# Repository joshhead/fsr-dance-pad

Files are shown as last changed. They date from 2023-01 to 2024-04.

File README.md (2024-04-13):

# FSR Dance Pad with Aluminum Frame

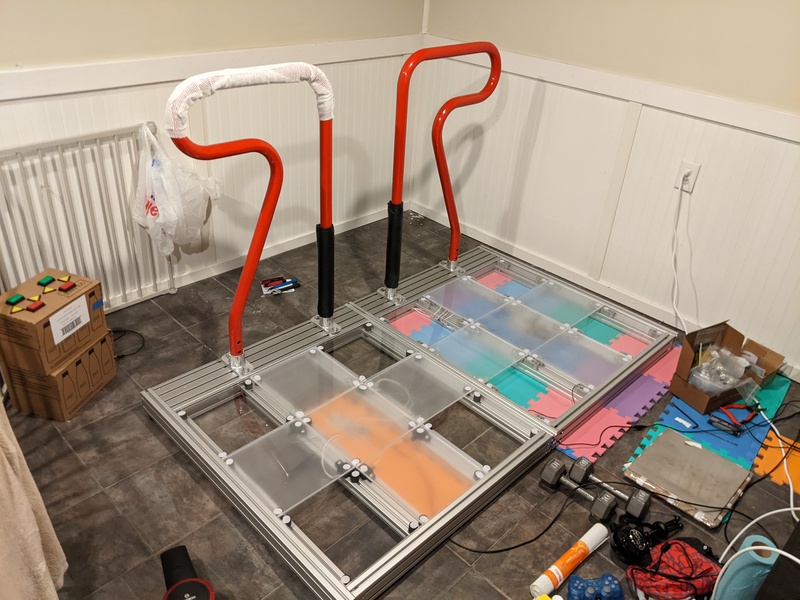
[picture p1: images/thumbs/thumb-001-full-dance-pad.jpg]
assembled dance pad
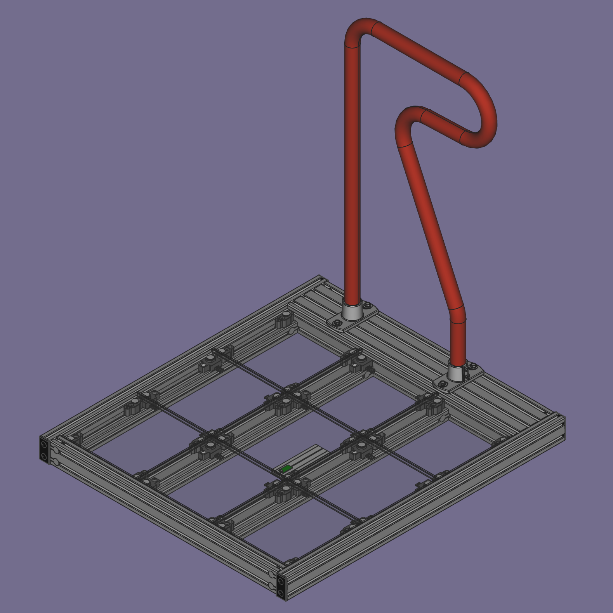
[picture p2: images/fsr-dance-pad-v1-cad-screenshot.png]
dance pad CAD model
[](./images/001-full-dance-pad.jpg) [](./freecad)

# Acknowledgements

This pad is essentially a fork of the RE:Flex dance pad (V2), with FSRs and teejusb's firmware.

I initially set out to build a RE:Flex, but ultimately made some changes.

My goals were

1. reduce BOM cost
2. support an arcade-style bar
3. minimize pad height to accomodate a low ceiling in my basement

Many of my design decisions were inspired and informed by ideas in the original RE:Flex, and even where I am happy with my changes, I'm usually giving up some desirable property in exchange. In several cases, trying to alter the design just made me realize why it was done that way in the first place. :)

# Differences from RE:Flex

* My frame is built with 15 series aluminum extrusions, which are 1.5 inches wide (38.1 mm). RE:Flex uses 40mm extrusions. TNutz was the cheapest hardware supplier I could find in the U.S. by a significant margin, and they do not carry 40mm extrusions, so I converted the frame to 15 series.
* My frame is assembled with anchor fasteners. RE:Flex uses joining plates on the bottom as well as inside corner gussets. The anchor fasteners save a small amount of height since there are no screws and joining plates underneath. It also allows the whole frame to sit flat on a foam mat since the bottom is all flush. When the frame is supported only at the corners (by rubber feet), I find it sqeaks. The joining plate plus corner gusset combo may do a better job of resisting twisting forces. The anchor fasteners require fewer screws, but also require machining on the extrusions.
* My pads include a set of Pump it Up GX bars, which I was lucky enough to snag on eBay after someone in the RE:Flex Discord pointed them out. They are mounted with railing flanges I found that happen to be the right size to fit both the bar and the extrusion. This meant getting beefy 3" by 6" extrusions for the back of the pads, which looks cool but increased the cost. I was super pleased to find that it all fits together well and feels sturdy. It would probably be more comfortable if it was height-adjustable, wider, and an inch or two further forward, which the RE:Flex bar does all of, so I'm not sure if this change was worth it! It was fun to design though. If you are unable to source an arcade bar but wanted to keep this form factor, you could build your own bar with pipe and elbow connectors.
* I modified the active and inactive panels to be flush with each other. RE:Flex inactive panels are 1mm higher than the active panels. This is nice for playing in socks, and less so in shoes since I can't feel where the panels are.
* Single-piece inactive panel standoffs. RE:Flex standoffs have some pieces that can be reused when switching from inactive to active panels, or iterating on the design. I came up with something that uses a little less plastic and can be printed in a single piece. It's also symmetrical so I don't need to worry about "left" and "right" versions. It sacrifices something in aesthetics since it looks a lot different from the active panel standoffs.
* Completely different electronics. The RE:Flex lighting looks amazing and its load cell based sensors have greater range and precision than the FSRs in my pad. However, due partly to the sweet lights and partly to semiconductor shortages, the cost of the RE:Flex electronics was very high in mid-2021, if you could even get all the parts. For a while I wanted 9 active panels, which RE:Flex didn't support yet (and still doesn't as of January 2023, but it is planned eventually).

# Other Designs

RE:Flex https://reflex.dance/

teejusb's FSR software https://github.com/teejusb/fsr

Dance pad by root670 https://github.com/root670/dance-pad

Bandit's travel pad (Build This Travel Pad) https://www.youtube.com/watch?v=y6wGYLE0YI4

Azirixx's build of Bandit's travel pad https://github.com/azirixx/easy-travel-pad-build

Sereni's FSR dance pad https://sereni.github.io/fsr-pad-guide/

Dom ITG's FSR dance pad https://www.youtube.com/playlist?list=PL2vUwLUVuyIy4CD8DEwS7oZ_Y41vyYWWy

Nato's metal travel pad https://github.com/natologic/MetalTravelPad

# Cost

I built two pads in the USA between 2021 and 2022 for around $1750 total.

# Bill of Materials

(See sourcing guide [here](./sourcing-guide.md) for product links and additional commentary.)

Frame Extrusions:
| Quantity | Profile | Length | Machining |
| --- | --- | --- | --- |
| 2 | 1515 (1.5" x 1.5") | 33 3/8"  | 4x counterbore |
| 2 | 1530 (1.5" x 3.0") | 33 3/8"  | 4x counterbore |
| 2 | 1530 (1.5" x 3.0") | 40 7/8"  | none |
| 1 | 1530 (1.5" x 3.0") | 33 3/8"  | 6x counterbore |
| 1 | 3060 (3.0" x 6.0") | 33 3/8"  | 6x counterbore |

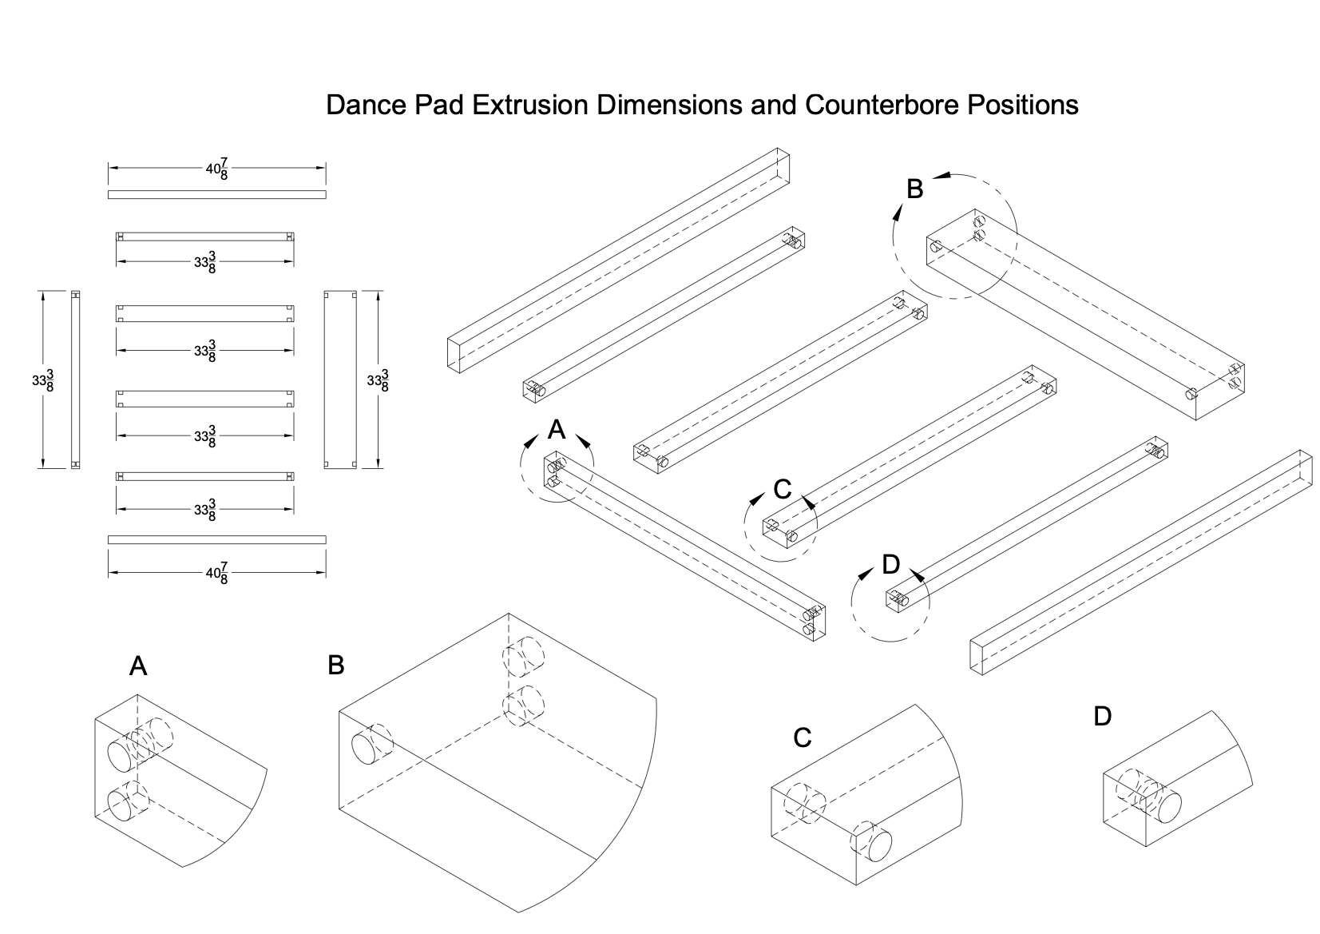
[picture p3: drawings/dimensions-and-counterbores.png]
dimensions and counterbores drawing


Frame Fasteners:
* 4 double anchor fastener assemblies for 1515 struts
* 4 wide double anchor fastener assemblies for 1530 struts
* 12 single anchor fastener assemblies for front and back

Frame support:

* Foam or rubber mat to support pad

  OR

* 4 rubber feet, 4 screws, 4 t nuts

  OR

* 4 leveling feet of some kind

Bar Assembly:
* 1 Pump It Up bar or DIY bar (use nominal 1 1/4" pipe, outer diameter of 1.66")
* 2 Hollaender® - Safety Rail Fitting - 1-1/4in. Base Flange Strctrual Slip-on Fitting
* 4 t nuts, 4 washers, 4 screws (5/16"-18 7/8"long)
* 2 3D printed screw aligners

Panels and standoffs:
* 9 11" x 11" x 0.472" (12mm) cast acrylic panels
* 36 t-nuts and 36 5/16-18 x 1" Button Head Socket Cap Screws to attach standoffs
* 20 3D printed inactive panel standoffs
* 16 3D printed active panel FSR holders
* 16 3D printed active panel standoffs
* 16 3D printed active panel standoff holders (8 of standoff-holder.stl and 8 of standoff-holder-mirrored.stl)
* 16 rubber bumpers with adhesive backing, 1/2" OD, 1/16" thick
* 36 pairs of hook and loop fastener circles, 20mm diameter (36 hook, 36 loop)

Sensors and electronics:
* 1 Teensy LC with pins
* 1 10ft USB micro cable
* Some 330 ohm resistors, the exact value isn't that important, anything 100 ohm to 1000 ohm is probably usable.
* 22awg solid core hookup wire
* 1 Solderless breadboard
* 16 Interlink FSR 402 Short FSRs with female connector with housing
* 1 3D printed breadboard platform
* 2 t nuts and 2 screws (5/16"-18 5/8" long) for breadboard platform
* Small zip ties
* 3D printed cable management clips

Tools:
* 3D printed hook and loop fastener aligners
* 3D printed strut spacers
* 3D printed standoff spacers
* Ball-end hex allen keys
* Wire cutters
* Wire strippers
* Deburring tool

# Build Instructions

Up front you'll need a 3D printed spacing tool for the struts and a round hex ball wrench.

First gather your parts and deburr them. I used needle nose pliers to pull off the big chunks and deburring tool to smooth out some rough edges. The anchors will not fit properly if there is too much debris. Remember that the deburring tool has two different angles on it and dragging it in one direction will cut deeper. I didn't find this to be as big of an issue as on plastic parts but it is still useful to be aware of.

Lay out your extrusions as they will be arranged. Check their orientation. Maybe some are scratched. Decide where you want the scratches to go.

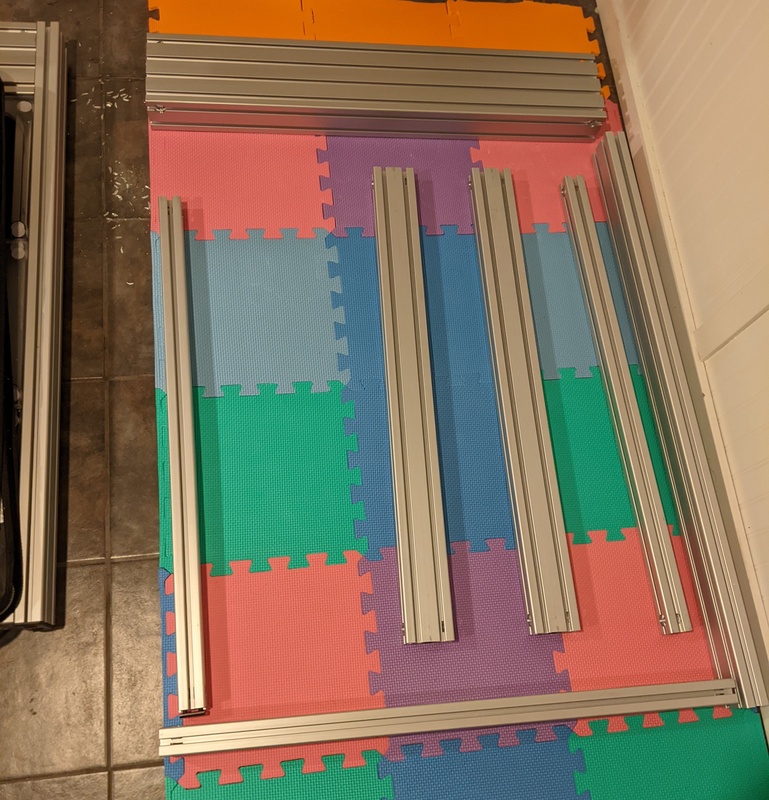
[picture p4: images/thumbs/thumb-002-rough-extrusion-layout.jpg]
rough extrusion layout


If you are using slide-in t nuts to attach the bar, feet, panel standoffs, breadboard platform, or any other accessories, insert them all now! They can't be added after joining the extrusions together. Roll-in t nuts are more expensive, but very convenient since they give you flexibility in the order of assembly or to add things on later. I used some heavy duty slide-in t nuts for the bar which I inserted at this point.

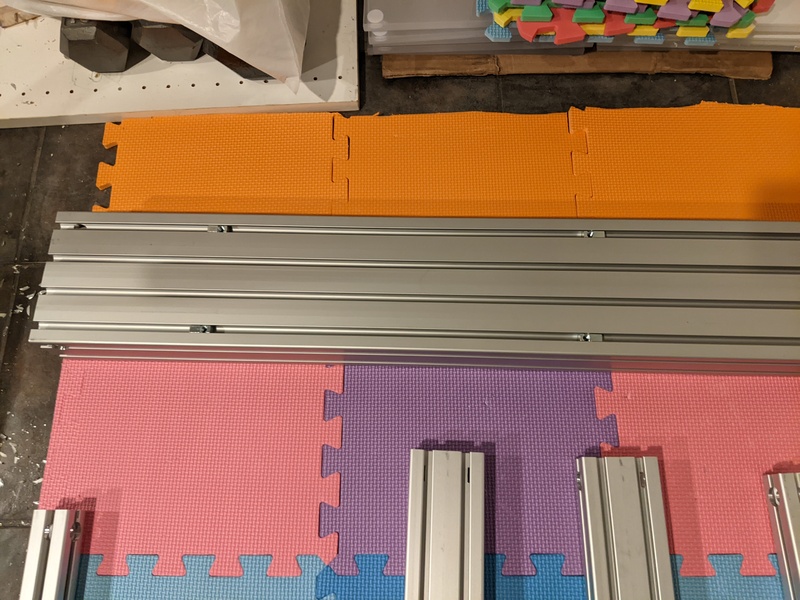
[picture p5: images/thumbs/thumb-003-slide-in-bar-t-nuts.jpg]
slide in bar t nuts


Gather your anchor fastener assemblies. Make sure they all match up and you have enough.

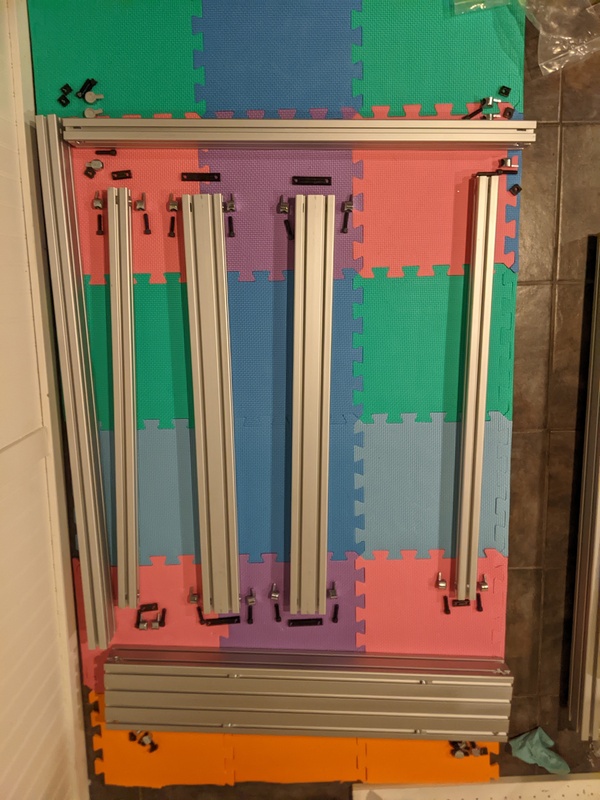
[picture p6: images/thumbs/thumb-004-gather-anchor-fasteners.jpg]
gather anchor fasteners


Assemble the anchor fasteners on the ends of the extrusions that have been machined to fit them. Pay attention to the direction of the t nuts. I put them on backwards a few times. Easy fix but annoying. Screw them together just slightly; they need to slide into place.

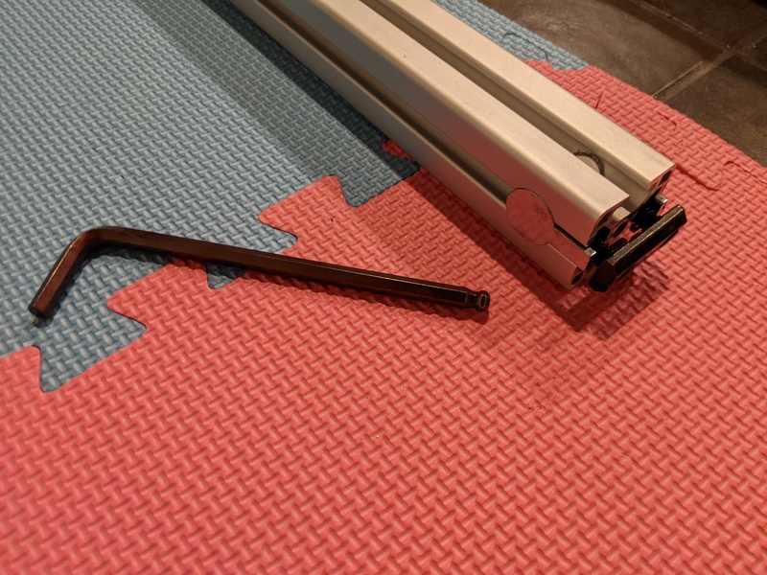
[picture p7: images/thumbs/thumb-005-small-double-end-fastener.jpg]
small double end fastener

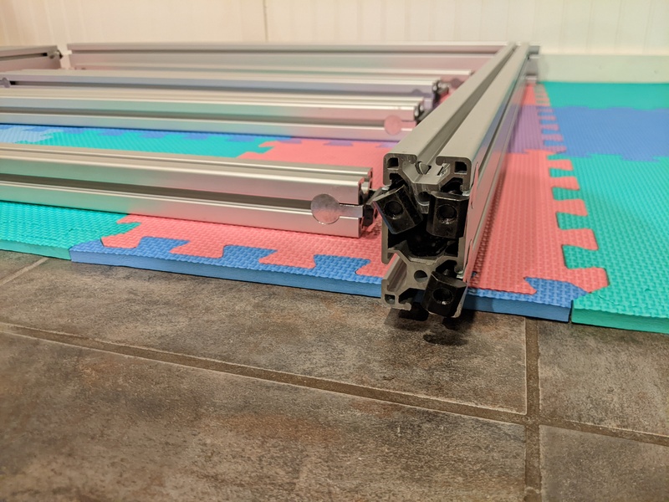
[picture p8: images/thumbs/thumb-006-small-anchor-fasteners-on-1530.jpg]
small anchor fasteners on 1530

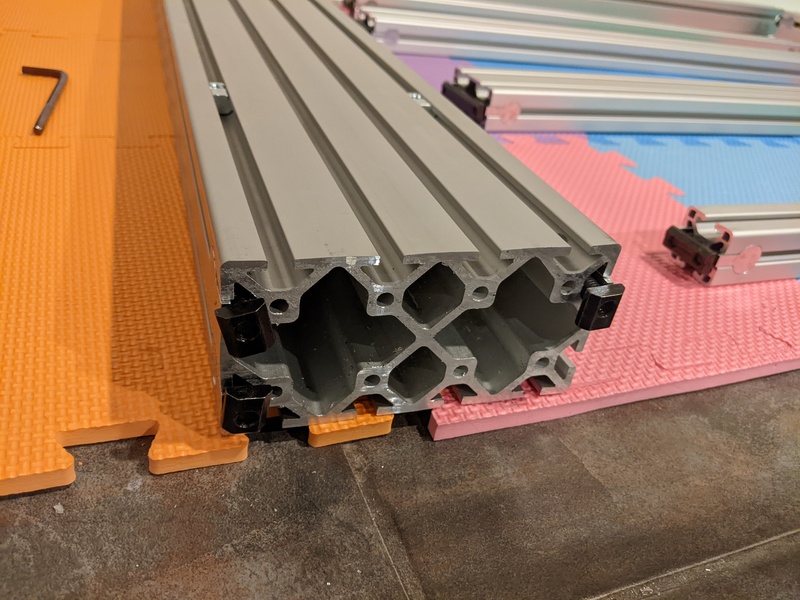
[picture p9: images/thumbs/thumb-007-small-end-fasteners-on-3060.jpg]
small end fasteners on 3060

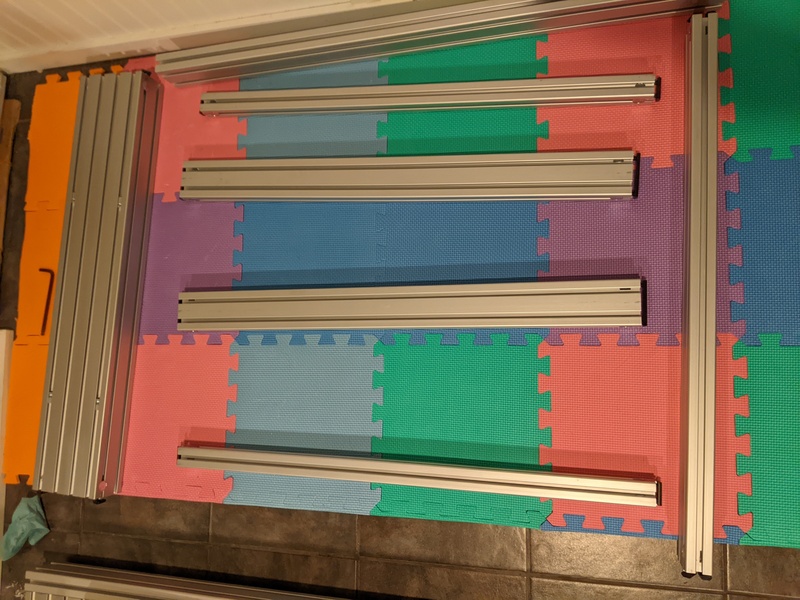
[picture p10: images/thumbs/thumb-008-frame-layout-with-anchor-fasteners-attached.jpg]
frame layout with anchor fasteners attached


Slide the four struts into the back and front extrusions. Or, depending on your perspective, slide the back and front pieces onto the struts. I had to loosen some of the screws a little bit; if they are too tight, the extrusions will not slide together.

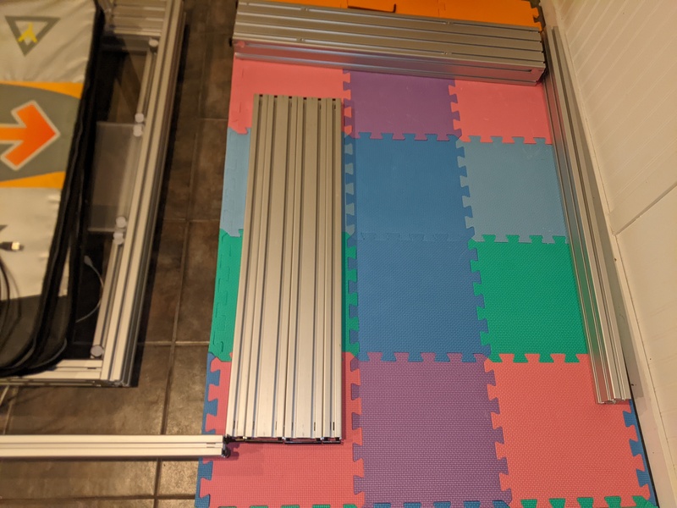
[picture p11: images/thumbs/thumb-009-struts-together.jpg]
struts together

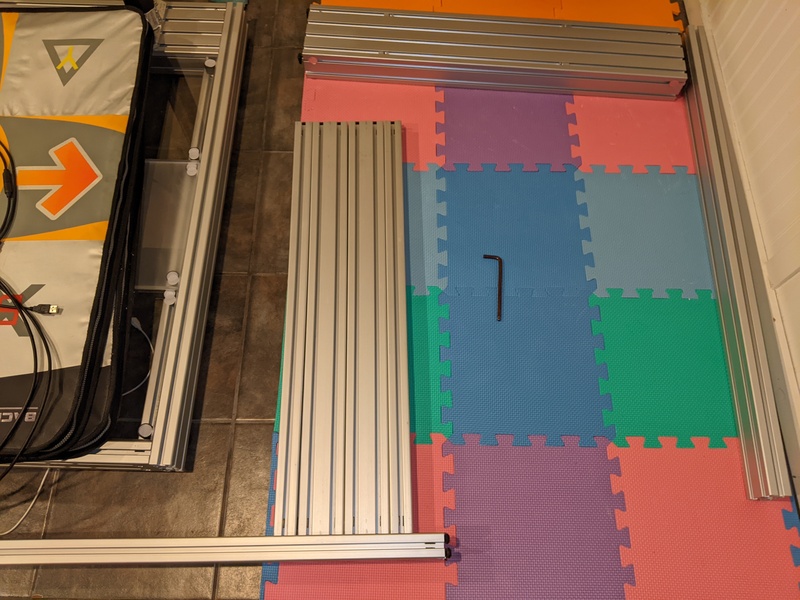
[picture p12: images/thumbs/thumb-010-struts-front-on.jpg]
struts front on

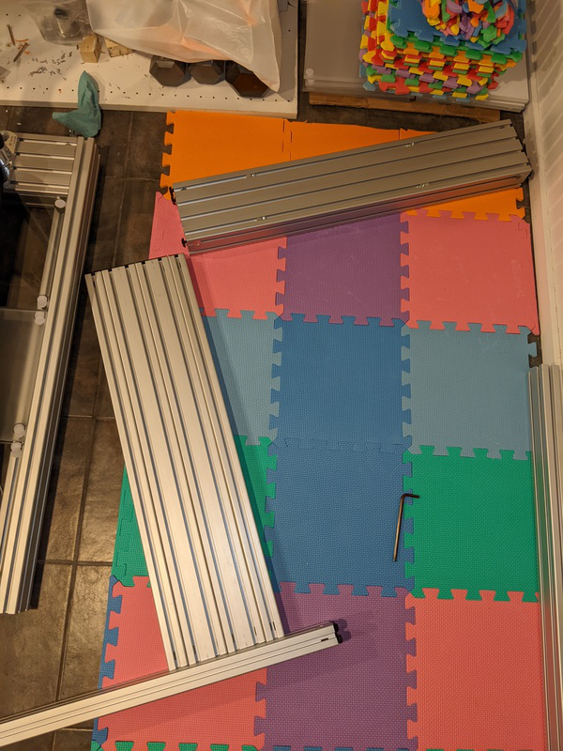
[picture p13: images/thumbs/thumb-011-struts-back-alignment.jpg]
struts back alignment

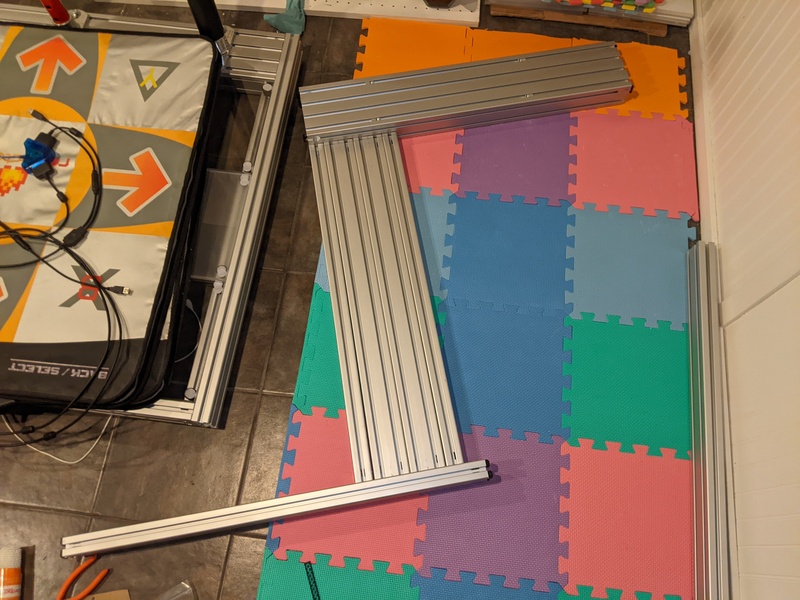
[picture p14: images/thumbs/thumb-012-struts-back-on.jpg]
struts back on

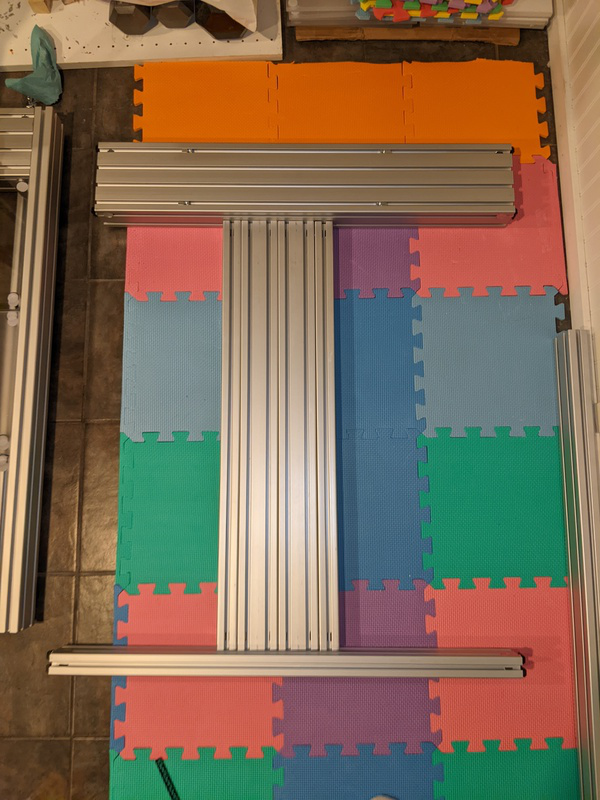
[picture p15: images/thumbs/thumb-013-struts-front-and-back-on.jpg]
struts front and back on


Now attach the left and right sides by sliding them on. In the pictures, I have only one side, because I am sharing a center piece between the player one and player two pads.

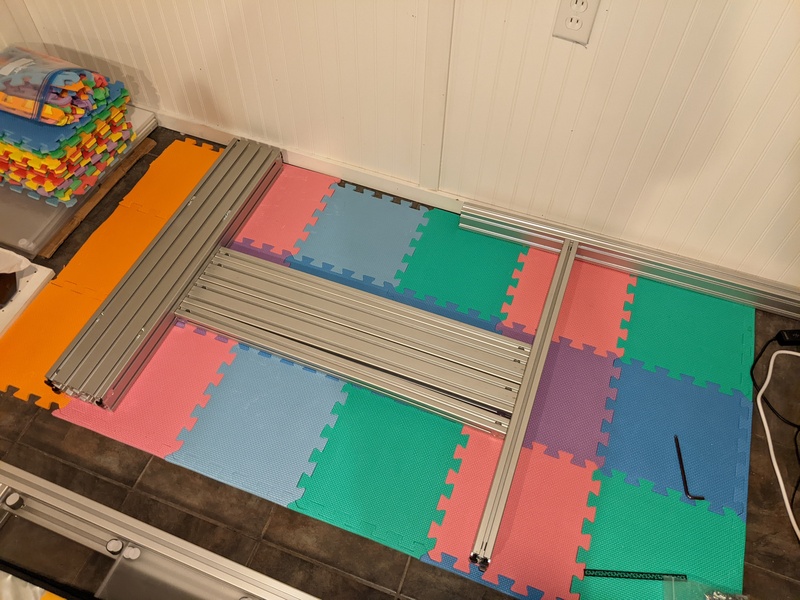
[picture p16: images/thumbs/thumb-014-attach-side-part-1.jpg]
attach side part 1

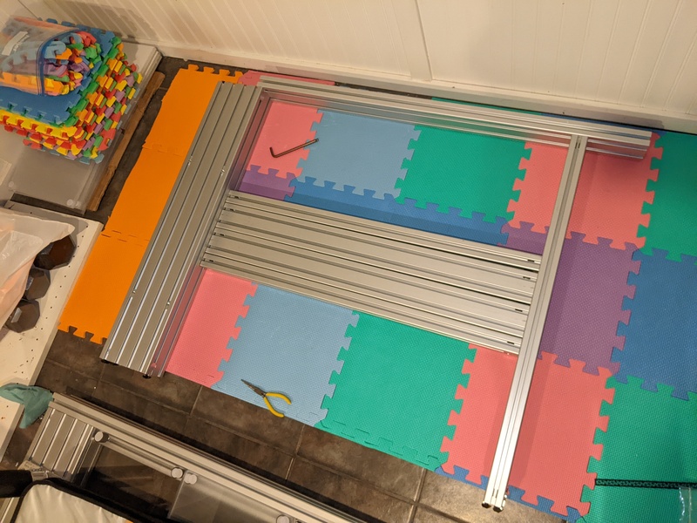
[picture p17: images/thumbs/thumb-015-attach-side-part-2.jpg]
attach side part 2

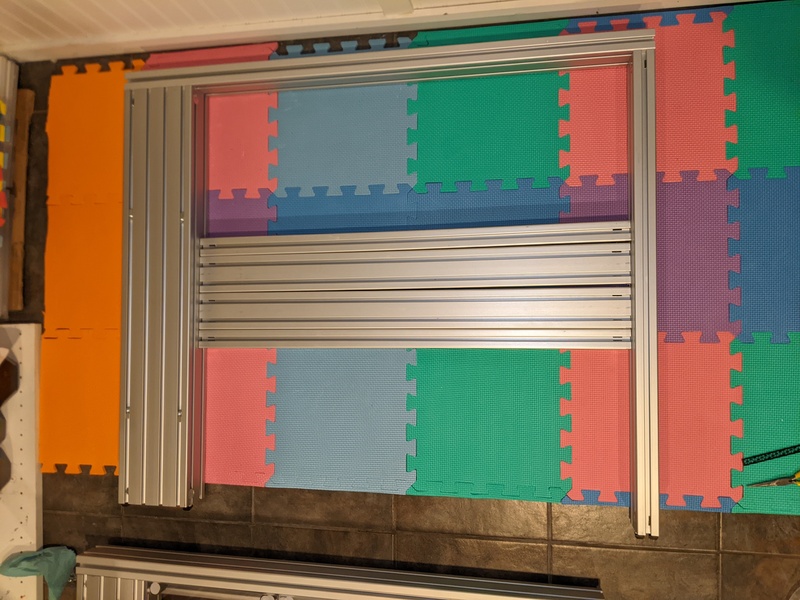
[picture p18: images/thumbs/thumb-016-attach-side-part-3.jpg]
attach side part 3


Once the outer pieces are slid on, evenly distribute the struts using the 3D printed spacer. Speaking from my experience, I recommend moving all of the struts into place before tightening any of them, as they will get progressively harder to adjust as more of them are tightened.

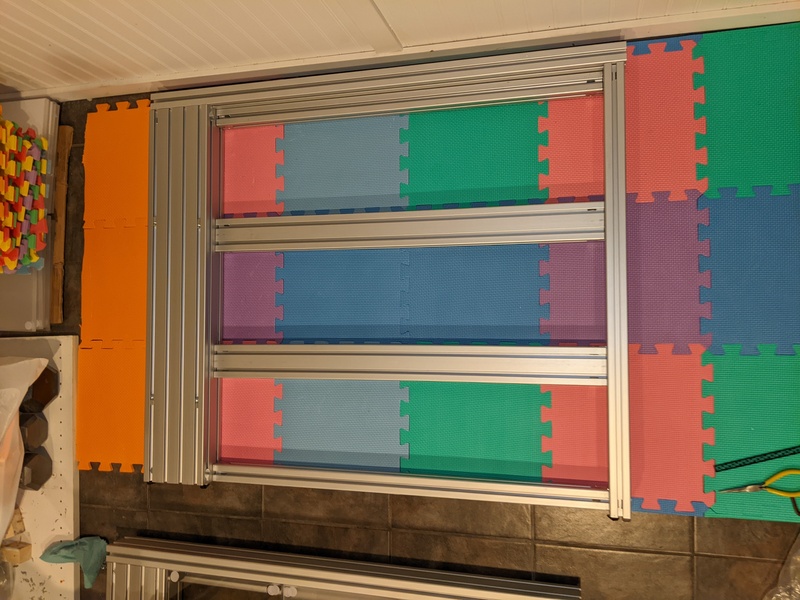
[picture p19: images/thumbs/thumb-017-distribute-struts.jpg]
distribute struts


Realize that everything may not be perfectly square at this point, so the struts may be farther apart at one end than the other. Check the spacing at both ends of the struts, not just in the center.

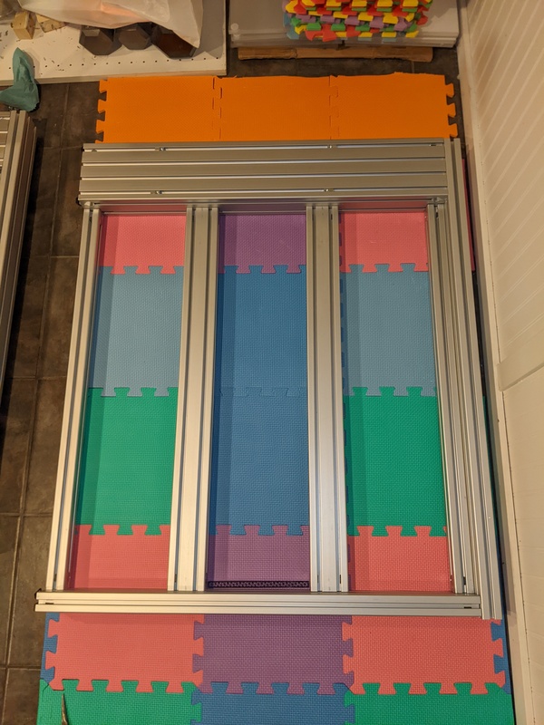
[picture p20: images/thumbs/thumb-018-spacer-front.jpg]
spacer front

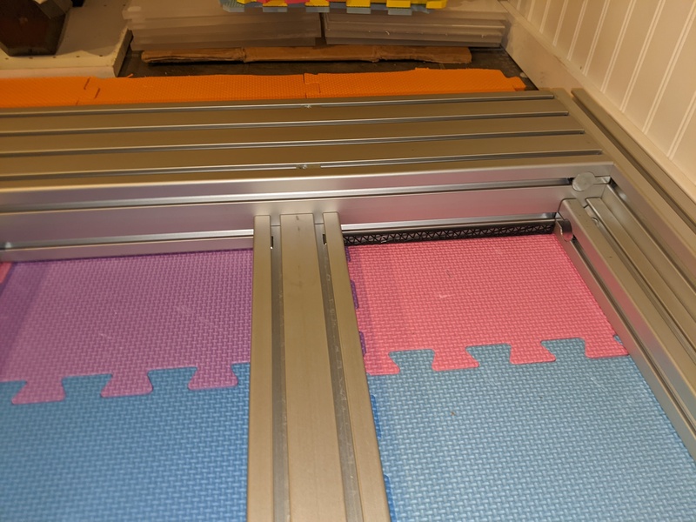
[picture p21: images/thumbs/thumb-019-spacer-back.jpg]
spacer back


The next part is a little tricky. Some fasteners are now unreachable: The outer extrusions block access to the screws on one side of the 1515 struts.

Fisrt, gently tighten the outside pieces, push the 1515 struts firmly against them, and tighten the screws on the inner sides of the 1515 struts that you can reach.

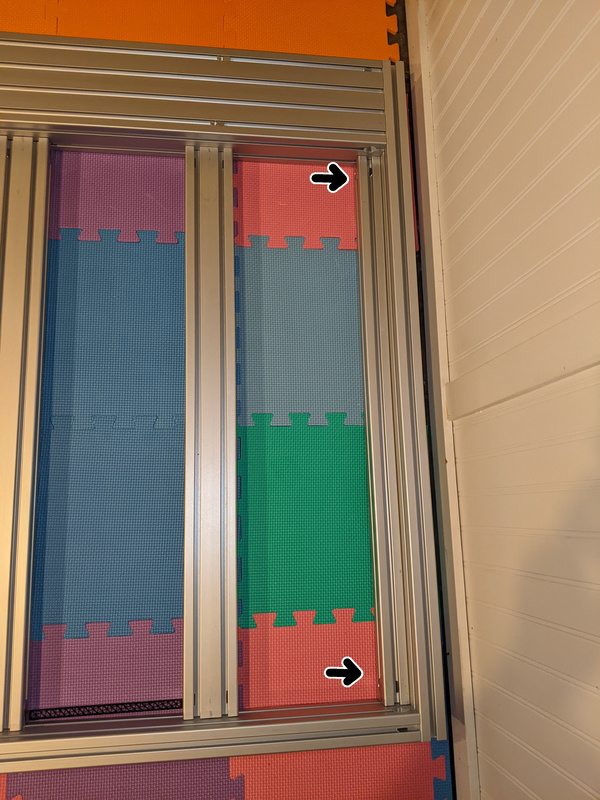
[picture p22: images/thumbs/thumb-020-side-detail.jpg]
side detail


Next, remove the outer extrusions to get access to the screws that were blocked and tighten them.

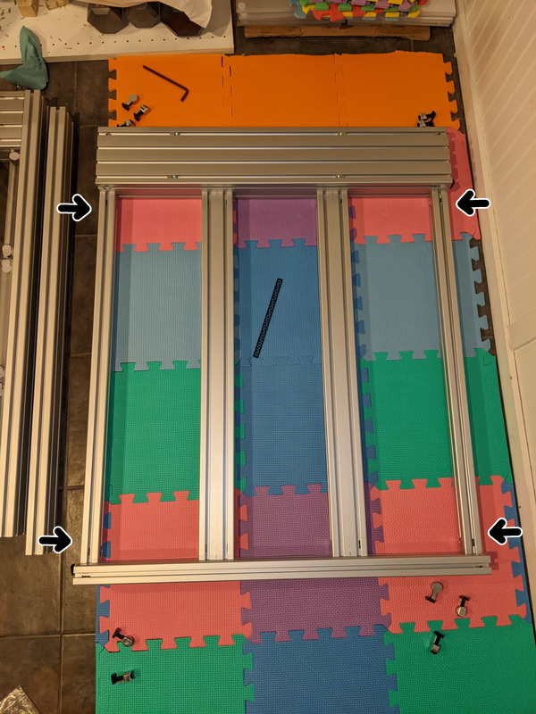
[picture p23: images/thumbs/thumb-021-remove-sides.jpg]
remove sides


This is also a good time to tighten the rest of the screws on the two middle struts.

Now put the sides back on, and tighten those as well. Note once again that in these pictures, one side is missing because the two pads will share an extrusion in middle.

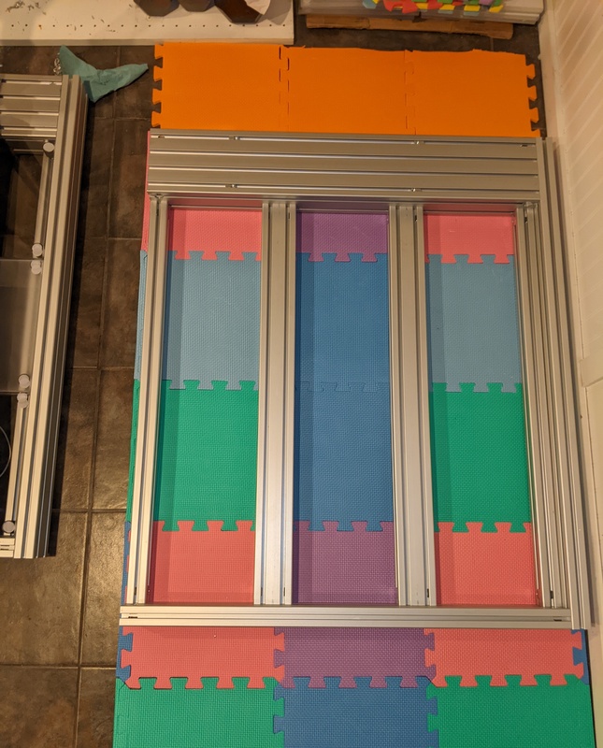
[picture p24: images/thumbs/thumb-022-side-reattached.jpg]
side reattached


Here we have the spacers/supports for the inactive panels. They align to the frame as well as to each other using a printed spacer (this is a different part than the spacer used to align the struts). They could be made more compact, but I wanted to leave enough room so that I could use the same hook and loop dot spacing if I ever upgraded to load cells.

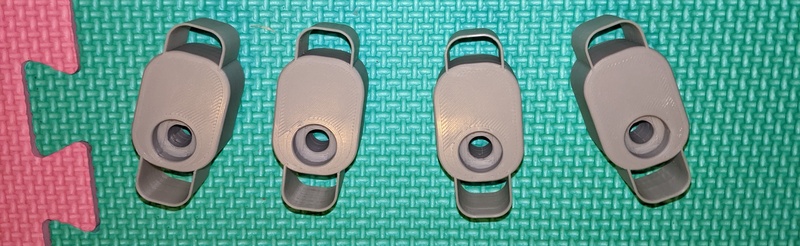
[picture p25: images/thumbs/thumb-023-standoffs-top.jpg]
standoffs top

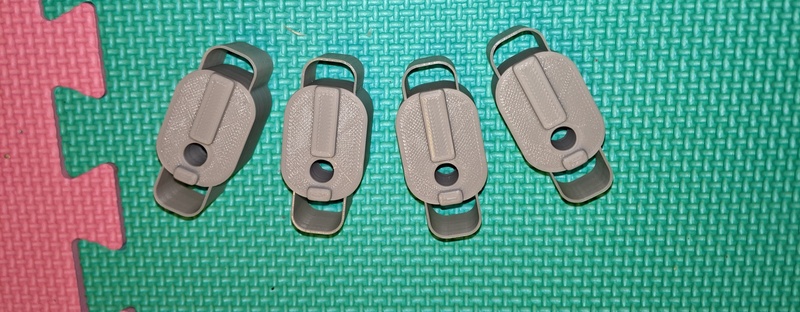
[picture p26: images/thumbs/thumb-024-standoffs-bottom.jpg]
standoffs bottom

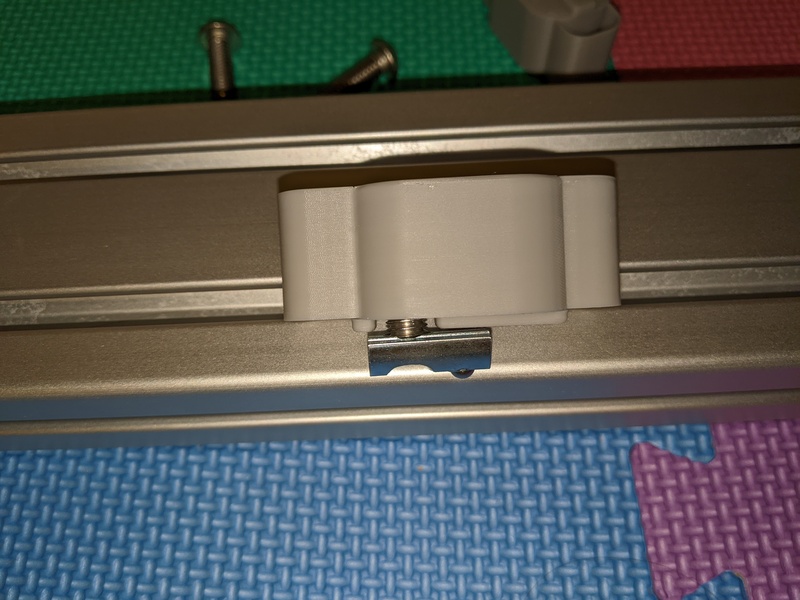
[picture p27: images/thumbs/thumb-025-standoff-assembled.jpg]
standoff assembled


Roll in the t nuts and screw the standoffs loosely in place. Align using the spacer, then tighten them in and apply the hook and loop dots. I put the hook dots on the standoffs and the loop dots on the panels. The dots go a little off center on the standoffs, aligned to the outer corners.

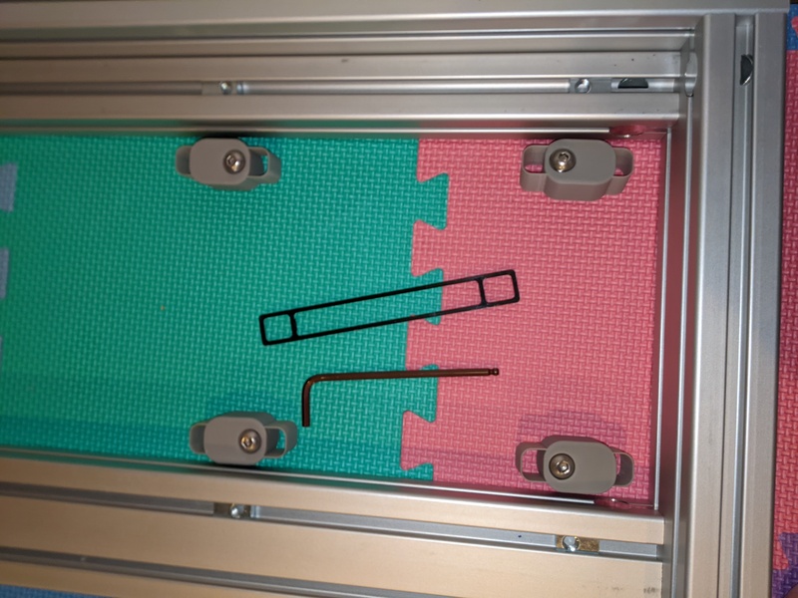
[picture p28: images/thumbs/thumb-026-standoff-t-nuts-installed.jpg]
standoff t nuts installed

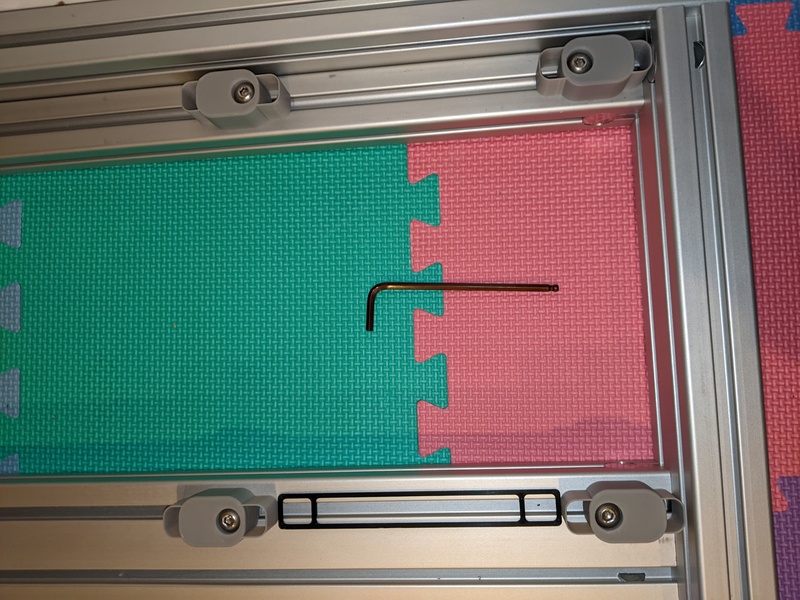
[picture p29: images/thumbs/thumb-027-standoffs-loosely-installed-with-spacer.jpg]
standoffs loosely installed with spacer

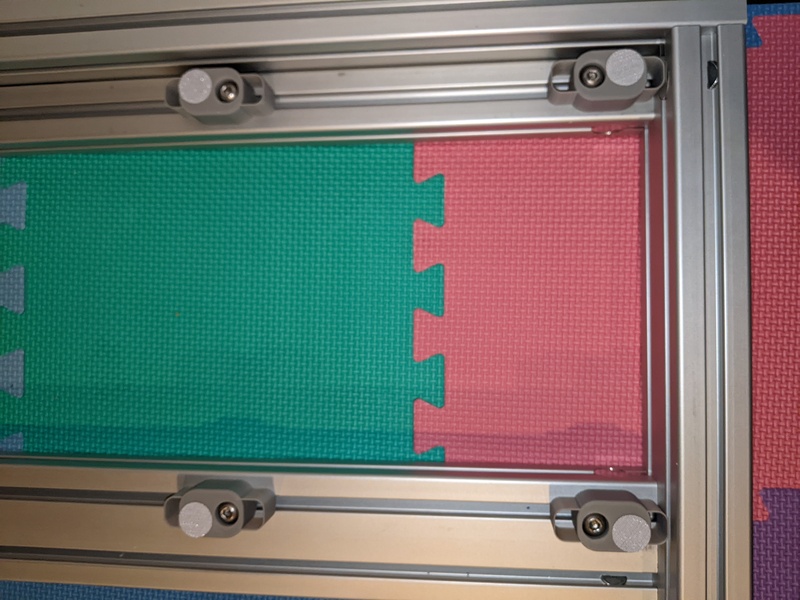
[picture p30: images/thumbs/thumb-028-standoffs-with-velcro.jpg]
standoffs with velcro


The panels come with slightly sharp edges from the saw cut. I chamfered the edges of my panels with a router at 45° angle. I have heard other people used sandpaper just to dull the sharp edges. The router was not difficult to use, but it's not strictly required and it was quite loud and somewhat messy.

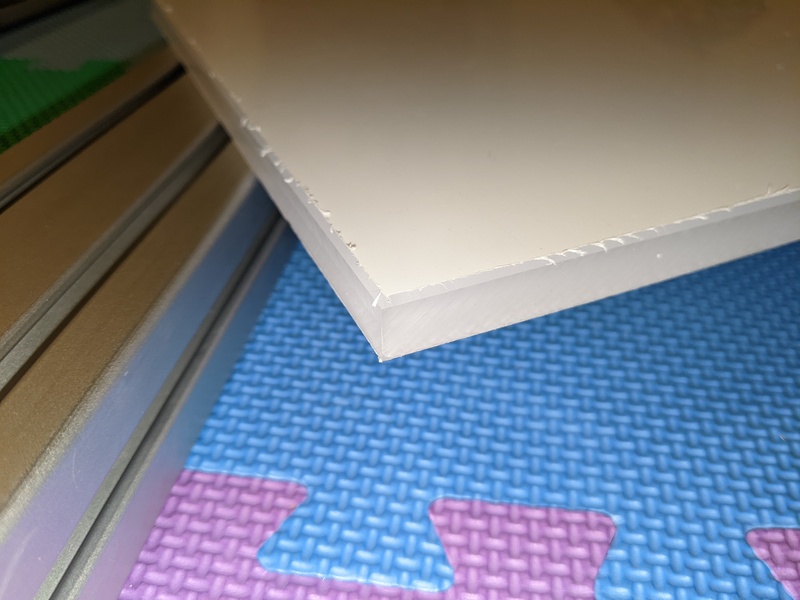
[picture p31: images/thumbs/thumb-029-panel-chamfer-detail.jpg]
panel chamfer detail


Remove the protective film. Apply hook and loop dots (loop side) using the printed spacers. Line up the dots and place the panel on top of the standoffs!

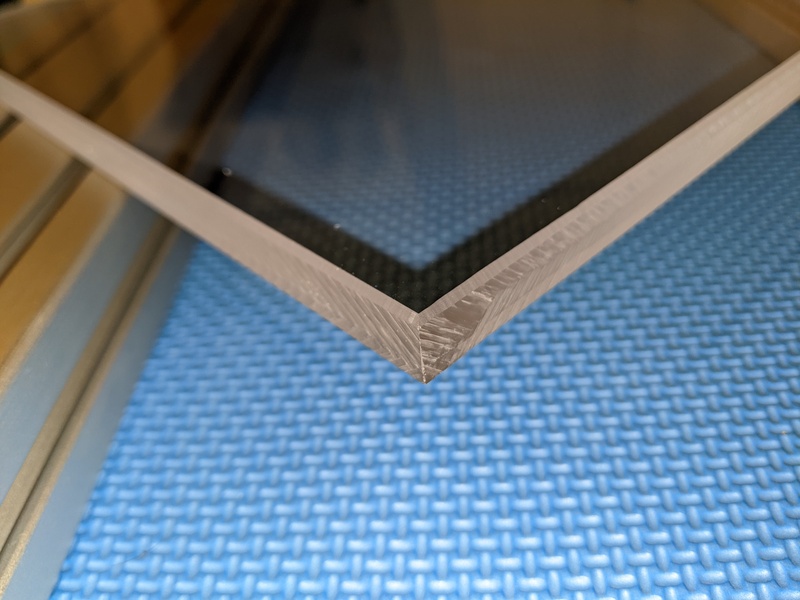
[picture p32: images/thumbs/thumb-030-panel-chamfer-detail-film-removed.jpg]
panel chamfer detail film removed

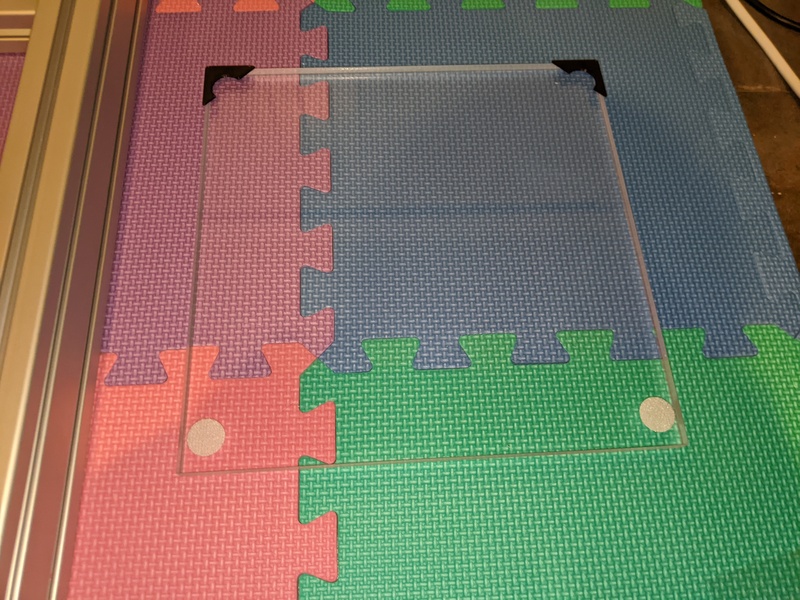
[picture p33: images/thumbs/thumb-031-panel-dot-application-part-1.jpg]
panel dot application part 1

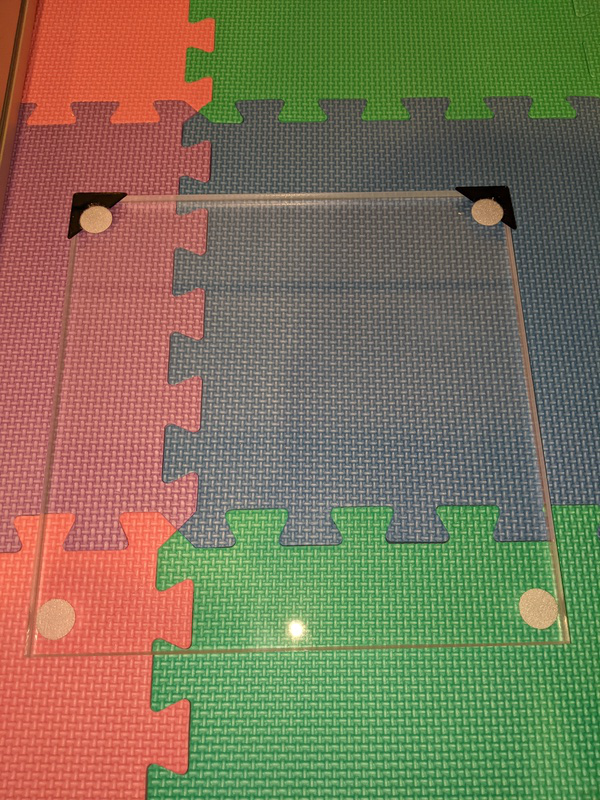
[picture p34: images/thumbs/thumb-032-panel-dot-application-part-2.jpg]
panel dot application part 2

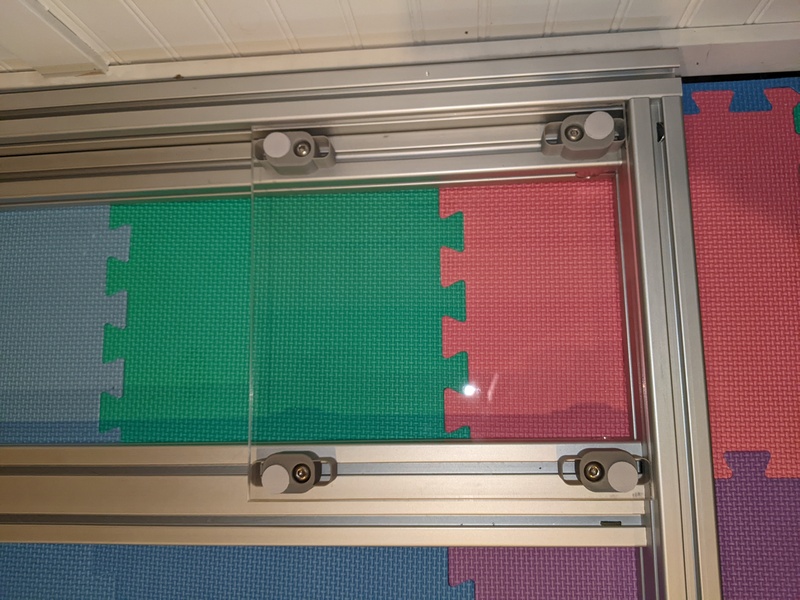
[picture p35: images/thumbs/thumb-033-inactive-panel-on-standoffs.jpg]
inactive panel on standoffs


Now the adapters for some active panels. These are redesigned from scratch to fit FSRs but are thoroughly inspired by the load cell holders on the RE:Flex dance pad. I made sure the spacing was such that if I one day wanted to replace them with the load cells from a RE:Flex board, a remixed RE:Flex load cell holder for 15-series extrusion would line up with the hook and loop dots in the same place. I'm using small round Interlink 402 short FSRs. Standard, not the X or UX variant (X and UX also work, but cost more).

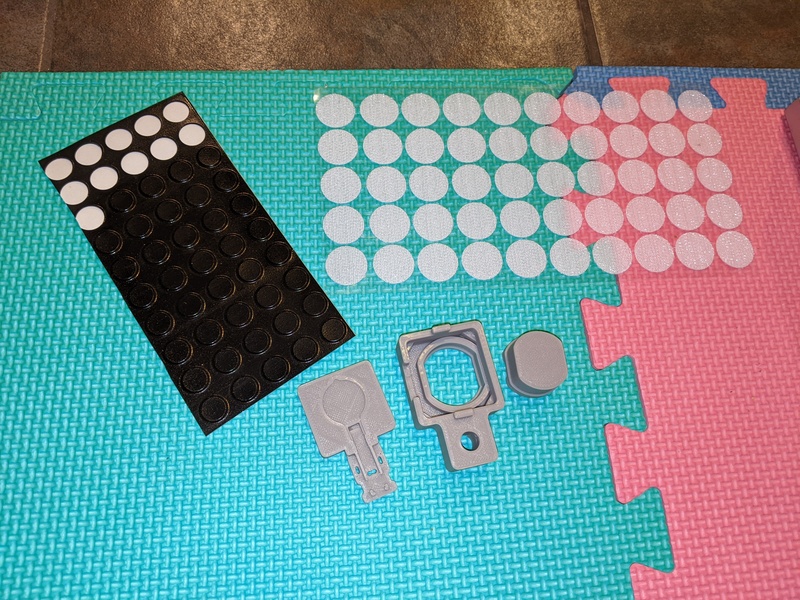
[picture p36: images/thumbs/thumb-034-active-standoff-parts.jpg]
active standoff parts


Add the rubber bumper to the bottom of the standoff part. There is a circle to help locate the center.

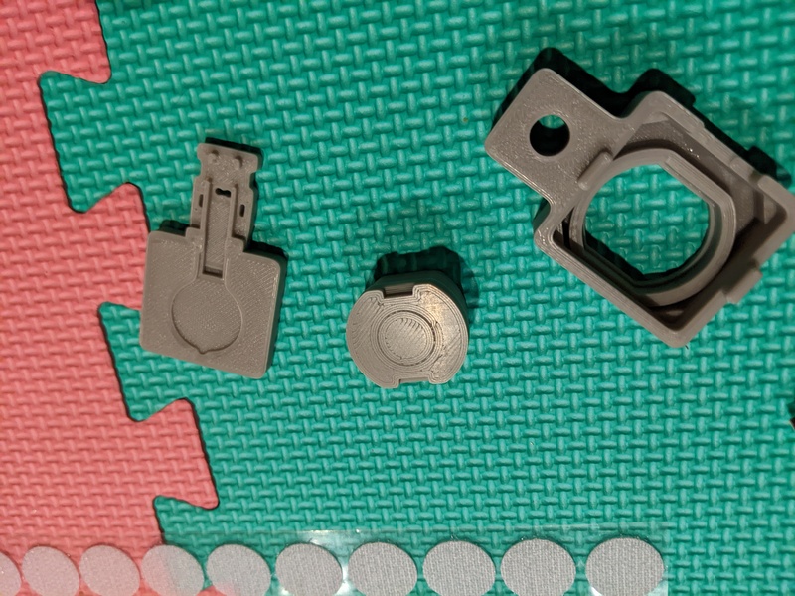
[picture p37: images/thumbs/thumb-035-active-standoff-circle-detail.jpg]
active standoff circle detail

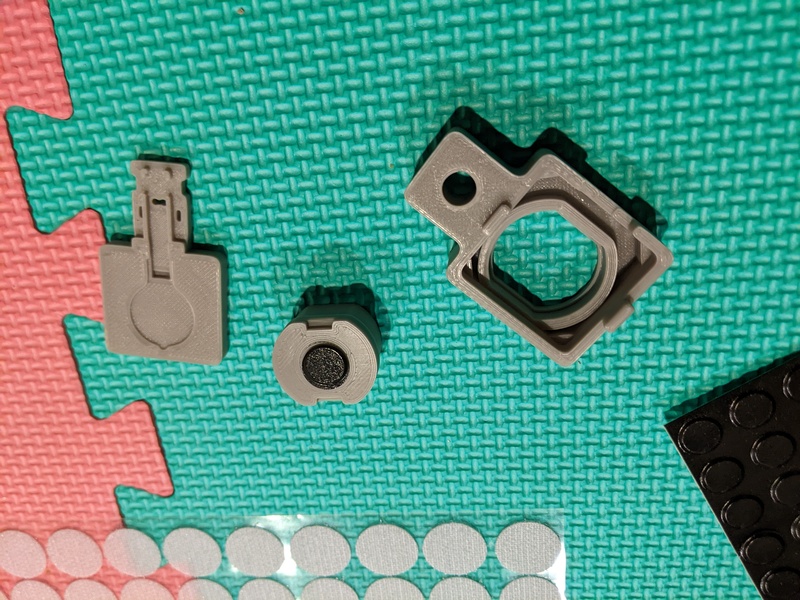
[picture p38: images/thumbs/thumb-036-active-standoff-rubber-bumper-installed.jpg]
active standoff rubber bumper installed


The FSRs come with adhesive applied to the bottom, but I am not sticking them in place. The FSR fits into a carefully-sized cutout that keeps it from moving around.

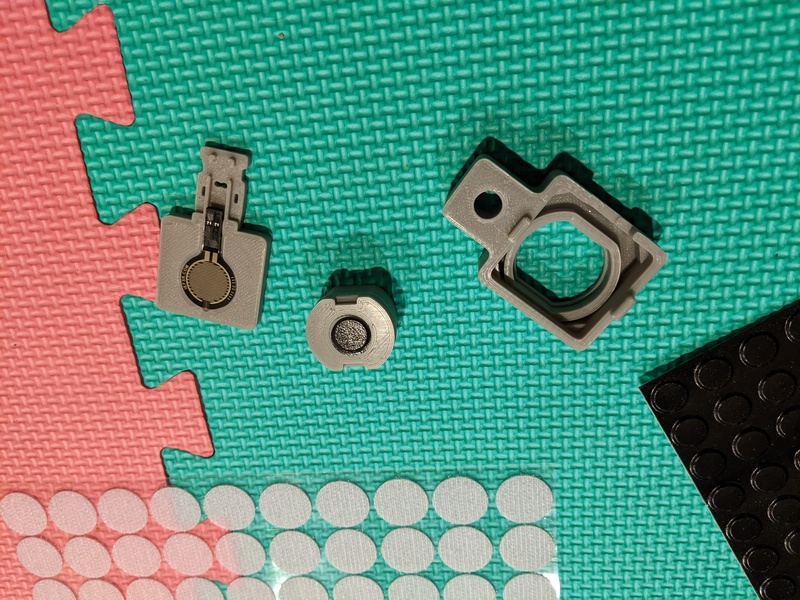
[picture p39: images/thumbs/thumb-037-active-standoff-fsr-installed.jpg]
active standoff fsr installed


Add the hook and loop dot to the top of the standoff. Fit the parts together and screw them in using a t nut. Take care about mirroring the parts and which one is left and right.

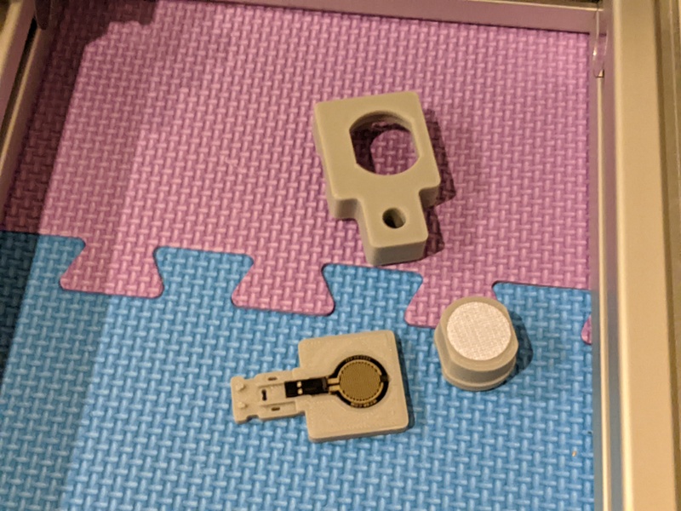
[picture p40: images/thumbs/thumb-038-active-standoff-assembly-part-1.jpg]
active standoff assembly 1

active standoff assembly 2
active standoff assembly 3
active standoff closeup

You can use the same 3D printed spacer as for the inactive panel standoffs.

active standoffs installed frame

Apply hook and loop dots (loop side) to another panel. It fits on top the same as with the inactive standoffs. It will have to come off to install the wiring, but feel free to do a test fit here.

As an aside, I sanded the underside of some panels with an orbital sander to give them a frosted look. I also sanded the top of the center panel, which makes it less smooth and perhaps counterintuitively helps reduce friction when playing in socks.

active standoffs with panel

Install the rest of the active and inactive standoffs.

It's possible to have a perfectly functional pad with only two FSRs per panel, on the inner corners (bordering the center panel).

My first pad has two FSRs per panel, my second has 4 FSRs per panel. Both work well. Using 4 FSRs per panel results in more uniform sensitivity across the panel, especially on the far edge, which can be useful for doubles play. The difference is not that dramatic though.

installing more standoffs

My solderless breadboard came with an adhesive pad on the bottom, which I used to stick it to a 3D printed platform.

broadboard platform

I recommend getting the firmware installed and testing it at your desk before proceeding to wire up the pad. This is currently outside the scope of the guide, but I may add more information about firmware and breadboard layout later.

breadboard on platform

To avoid having to crimp a connector onto every wire, I used solid core hookup wire, which fits snugly into both the female connector on the FSR and into the solderless breadboard.

fsr wire insert closeup

After plugging in the wires, use the provided mounting points to secure them with small cable ties.

fsr wiring cable ties

I designed these clips that snap into the slot of a 15 series extrusion. Use a generous amount of these to help keep the wires tidy.

cable clips
cable clips example

At first, I was routing the wires so that they did not cross gaps in the middle of panels, but later gave up on this plan since it was using so much extra wire. Use whatever approach feels right to you here.

pad with wires

If you tested your electronics in advance, you may have a working pad at this point! Plug it into a computer and test to see if everything is connected correctly and whether any panels are sticking. I had to file a few rough edges down on the 3D printed parts to make sure everything could move smoothly.

You can also take this opportunity to calibrate the trigger threshold with a 5 or 10 pound weight.

threshold calibration

At this point you need some way to route the USB cable to the outside of the frame. You have a couple of options.

If you install feet under the frame, you can run the cable through the gap underneath.

cable under frame

I used rubber bumpers for feet, that each attached with a screw to a t nut on the underside of the frame. I had a large 3D printed shim for one corner since my floor was not level at all. 

rubber feet

If you place the pad on foam or rubber surface like a playroom mat, gym floor mat, or horse stall mat, you may prefer to route the cable through a hole in the frame.

To make room for the cable to fit, you can remove two of the anchor fasteners on the front of the frame, as I did. This leaves space to route the cable through. I probably wouldn't recommend this if the pad is only supported by feet at the corners, since it will make the frame less rigid.

anchor fasteners removal detail
cable through frame top
cable through frame front

Finish installing the rest of the acrylic panels if you haven't, and the pad should be ready for nobar play! You may wish do some playtesting at this time before adding the bar.

nobar ready

I am not a Pump It Up expert, but I understand that the bars I got are from a Pump It Up GX cabinet. There is another piece (which I do not have) that bolts to the dancing stage, and I am using railing flanges for structural pipe instead. The flanges are not designed to fit precisely this size tube or specifically to attach to t slot extrusions, but the dimensions are close enough to work well. I chose this flange in particular because of the spacing between the mounting holes.

bar leaning

The 3D printed parts here are to help keep the screws aligned in the oversized holes, and also to help prevent scratches on the 3060 extrusion. Because the slots in the flanges are so wide, I added some thick washers to increase the contact area. I used different screws and t nuts for the bar mount than for the rest of the pad. I was going for something more heavy duty. It has worked well, but it may be overkill.

bar mounting hardware
bar mounting hardware 2

Install both flanges on the bar before screwing them down. Make sure the set screws on the flanges are loosened. It's a snug fit. I found that running a deburring tool around the top opening of the flange also helped slightly with the fit.

flange installation

Place the screw aligners under the flanges and set the bar on top of the back extrusion. Slide the t nuts into place under the holes.

bar installation part 1

Add the washers and screws. If you leave them a little loose, you can slide the bar sideways to adjust the position before tightening them all down.

bar installation part 2
bar installation part 3
all bar fasteners

Tighten the set screws on the flanges.

flange set screw detail

Now enjoy some dance gaming on your new dance pad!

clip of Josh playing Disco Pop 77

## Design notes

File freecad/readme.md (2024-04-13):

# FreeCAD Model

My original CAD models were incomplete, but I remodeled the pad in 2024. I believe the parts and placement are accurate, but it's possible there are some mistakes.

Some tools are missing for now.
* 3D printed hook and loop fastener aligners
* 3D printed strut spacers
* 3D printed standoff spacers

fsr-dance-pad.FCStd contains links to files in the parts-and-subassemblies folder. If you download fsr-dance-pad.FCStd without also downloading the parts-and-subassemblies and all its contents to the same parent folder, it will not display properly when opened.

It should work in FreeCAD 0.21.0 or newer.

A copy of the assembly is also exported as a STEP file in the [step](../step) folder.

[dance pad CAD model](../images/fsr-dance-pad-v1-cad-screenshot.png)

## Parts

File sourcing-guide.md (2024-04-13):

The following are some links to parts and some of my thoughts and notes related to them.
The list here matches the design in the photos and guide, but I do have some ideas for future changes,
especially with bar. If you have questions or see mistakes, please feel free to reach out.

| Category | Part | Quantity | Recommended Source | Notes |
| --- | --- | --- | --- | --- |
| Frame | T-Slotted Aluminum Extrusion 1515L (1.5" x 1.5"), 33 3/8" length, with 4 counterbores | 2 | [TNUTZ](https://www.tnutz.com/product/ex-1515l/) | Frame bottom. On tnutz, select 13/16" Counterbore @ "A" & "C" for both ends. |
| Frame | T-Slotted Aluminum Extrusion 1530UL (1.5" x 3.0"), 33 3/8" length, with 4 counterbores | 2 | [TNUTZ](https://www.tnutz.com/product/ex-1530ul/) | Frame bottom. On tnutz, select 13/16" Counterbore @ "E" & "H" for both ends. |
| Frame | T-Slotted Aluminum Extrusion 1530UL (1.5" x 3.0"), 33 3/8" length, with 6 counterbores | 1 | [TNUTZ](https://www.tnutz.com/product/ex-1530ul/) | Frame front. On tnutz, you want 13/16" Counterbore @ "F", "G", & "I" on both ends, but that's not an option on the product page. You can select 13/16" Counterbore @ "F", "G", "I" & "J", and add an order note at checkout explaining that for the 33 3/8" 1530UL extrusion with "F", "G", "I" & "J" counterbores you would actually like 13/16" Counterbore @ "F", "G", & "I" on both ends, no "J" counterbores. |
| Frame | T-Slotted Aluminum Extrusion 3060 (3.0" x 6.0"), 33 3/8" length, with 6 counterbores | 1 | [TNUTZ](https://www.tnutz.com/product/ex-3060/) | Frame back. On tnutz, you want 13/16" Counterbore @ "K", "L", & "O" on both ends, but that's not an option on the product page. You can select 13/16" Counterbore @ "K", "L", "O" & "P", and add an order note at checkout explaining that for the 2 33 3/8" 3060 extrusion you would actually like 13/16" Counterbore @ "K", "L", & "O" on both ends, no "P" counterbores. |
| Frame | T-Slotted Aluminum Extrusion 1530UL (1.5" x 3.0"), 40 7/8" length | 2 | [TNUTZ](https://www.tnutz.com/product/ex-1530ul/) | Frame sides. No machining options needed. |
| Frame Fasteners | 1.5" Double Anchor Fastener Assembly (short) | 4 | [TNUTZ](https://www.tnutz.com/product/afd-015-a/) | For attaching the 1515 pieces of the frame bottom to the frame front/back. |
| Frame Fasteners | 3" Double Anchor Fastener Assembly (long) | 4 | [TNUTZ](https://www.tnutz.com/product/afd-015-b/) | For attaching the 1530 pieces of the frame bottom to the frame front/back. |
| Frame Fasteners | 15 Series Anchor Fastener Assembly | 12 | [TNUTZ](https://www.tnutz.com/product/af-015/) | For attaching the front/back pieces of the frame to the frame sides. |
| Frame Support | Foam mat OR tread strip OR leveling feet OR rubber bumper feet | | | I like the foam tiles. I have interlocking EVA foam tiles under my pad that used to be a kid's play mat. I also tried feet made from rubber bumpers held on with screws and t nuts. They were a bit difficult to install once the frame was assembled. The stock RE:Flex leveling feet should fit if you can find them. Or a tnutz representative suggested using rubber tread strip on the bottom, which I bet would work fine ( [https://www.tnutz.com/product/bum-015-ts/](https://www.tnutz.com/product/bum-015-ts/) ). Anything that people suggest putting an arcade pad on would probably work (horse stall mats?). |
| Frame Extras | 15 Series Black Plastic End Cap (1.5" x 3") | 4 | [TNUTZ](https://www.tnutz.com/product/ec-015/) | For covering the exposed ends of the side extrusions. |
| Bar | Pump It Up GX bar or 3 pieces of 1 1/4" nominal pipe, acutal pipe outer diameter 1 5/8" | 1 | | I was lucky enough to find some used arcade bars on eBay, so that it what my design is based around. This is not required. Consider using some 1 1/4" (nominal) plumbing or structural pipe. e.g. [https://www.homedepot.com/p/The-Plumber-s-Choice-1-1-4-in-x-36-in-Black-Steel-Pipe-1136PBL/307789989](https://www.homedepot.com/p/The-Plumber-s-Choice-1-1-4-in-x-36-in-Black-Steel-Pipe-1136PBL/307789989) or [https://www.lowes.com/pd/B-K-SteelTek-1-1-4-in-x-36-in-Galvanized-Steel-Structural-Pipe/1000057737](https://www.lowes.com/pd/B-K-SteelTek-1-1-4-in-x-36-in-Galvanized-Steel-Structural-Pipe/1000057737) . You can make a bar with two 36" and one 24" pipe sections, or cut custom lengths to your preferences. |
| Bar | Structural pipe fitting elbow connector for 1 1/4" nominal pipe size, actual pipe outer diameter of 1 5/8" (only for DIY bar) | 2 | | I hesitate to recommend a specific part here because I haven't tested them. The match for the base flange would be [https://www.grainger.com/product/HOLLAENDER-Structural-Pipe-Fitting-Elbow-54WK14](https://www.grainger.com/product/HOLLAENDER-Structural-Pipe-Fitting-Elbow-54WK14) . A similar part on McMaster is [https://www.mcmaster.com/4698T33/](https://www.mcmaster.com/4698T33/) . If you get threaded black steel pipe, you could try an elbow fitting like this [https://www.homedepot.com/p/Southland-1-1-4-in-x-1-1-4-in-Black-Malleable-Iron-90-degree-FPT-x-FPT-Elbow-Fitting-520-006HN/100111484](https://www.homedepot.com/p/Southland-1-1-4-in-x-1-1-4-in-Black-Malleable-Iron-90-degree-FPT-x-FPT-Elbow-Fitting-520-006HN/100111484) |
| Bar | Structural pipe fitting base flange for 1 1/4" nominal pipe size, actual pipe outer diameter of 1 5/8" | 2 | [Grainger](https://www.grainger.com/product/HOLLAENDER-Structural-Pipe-Fitting-Base-54WK21) | The Hollaender part is the one I use. Likely compatible alternative part I have not tested: [https://www.mcmaster.com/4698T155/](https://www.mcmaster.com/4698T155/) |
| Bar Fasteners | High-torque T-Nut with 5/16-18 thread size | 4 | [TNUTZ](https://www.tnutz.com/product/ht-015/) | I chose extra strong t-Nuts to mount the bar, but the regular roll-in t-nuts would probably be fine here. |
| Bar Fasteners | Oversized washers, for M8 Screw Size, 8.4 mm ID, 24 mm OD | 4 | [McMaster-Carr](https://www.mcmaster.com/95211A180/) | Because the slots on the base flange are fairly large, the oversized washers help the screws to make contact. |
| Bar Fasteners | 5/16-18 x 7/8" Flanged Hex Head Screws | 4 | [McMaster-Carr](https://www.mcmaster.com/92979A157/) | I was looking for something with a wider head that could be tighted down securely, and these work well. 5/16-18 x 7/8" Button Head Socket Cap Screws might be good enough. |
| Active Panels | 11" x 11" x 0.472" (12mm) cast acrylic panels | 4 | [TAP Plastics](https://www.tapplastics.com/product/plastics/cut_to_size_plastic/acrylic_sheets_cast_clear/510) | Tap Plastics is a well-known and convenient to use store, but not very cheap. You may be able to find a better deal if you search for local acrylic suppliers. |
| Inactive Panels | 11" x 11" x 0.472" (12mm) cast acrylic panels, or 11" x 11" x 0.25" (6.35mm) 6061 aluminum plate. | 5 | [TAP Plastics](https://www.tapplastics.com/product/plastics/cut_to_size_plastic/acrylic_sheets_cast_clear/510) | I found the plastic to be perfectly usable, cheaper, and easier to work with. The metal panels do look extremely cool though. Aluminum needs to be painted or anodized in order to keep black aluminum oxide dust from rubbing off on your socks or shoes. |
| Panel Mounting | Drop-in or Slide-in T-Nut with 5/16-18 thread size | 36 | [TNUTZ](https://www.tnutz.com/product/db-015/) | You can save some money by using the standard or economy t-nuts (https://www.tnutz.com/product/et-015/) instead of the slide-in t-nuts with the spring ball, but they will be less convenient to work with. |
| Panel Mounting | 5/16-18 x 1" Button Head Socket Cap Screws | 36 | [TNUTZ](https://www.tnutz.com/product/imperial-button-head-ss/) | |
| Panel Mounting | Rubber bumpers with adhesive backing, 1/2" OD, 1/16" thick | 16 | [McMaster-Carr](https://www.mcmaster.com/95495K18-95495K181/) | |
| Panel Mounting | PLA 3D Printer filament, 1KG roll | 2 | [Amazon](https://www.amazon.com/DURAMIC-3D-Filament-Printing-Dimensional/dp/B07TW9KTVV) | Depends on your print settings, but you will probably need 1 to 2 1KG spools. |
| Panel Mounting | Hook and Loop or 3M Dual Lock Circles, 20mm diameter | 72 | | Make sure you have enough complete pairs (some spares would be a good idea too). Dual lock are symmetric so you will need 72 pieces to fit in the 36 corners of 9 panels. For Velcro or generic hook and loop, you will need 36 hook and 36 loop pieces. I ordered these generic ones: https://www.amazon.com/gp/product/B08G873CGJ They were cheap and work OK but the adhesive isn't good enough and eventually they start to gradually slide out of place. 3M Dual Lock is great but quite a bit more expensive. Small note, regular size Dual Lock is thicker than Velcro (about 5mm mated). The "low-profile" Dual Lock is about the same thickness as Velcro (about 3mm mated), but is harder to find, may be more expensive, and can be damaged pretty easily. I also tried https://www.itapestore.com/velcro-brand-hook-or-loop-coins-with-72-high-temp-adhesive-three-quarter-inch which seem to have a nice quality adhesive but I haven't tested them enough to say if they're worth the price. If I ever redesign the mounts, a likely change will be to use bigger hook and loop dots. |
| Electronics | Arduino-compatible development board with USB HID support | 1 | [PRJC](https://www.pjrc.com/store/teensy41_pins.html) | Many options here. Teensy 4.1 is well-supported by Teejusb's FSR firmware and has enough analog inputs to do 16 independent sensor inputs. It is plenty fast enough to control lots of colorful lights. If you want to save a few dollars, a Pro Micro clone (e.g. https://www.aliexpress.com/item/32840365436.html) is a valid choice with 9 analog pins but not fast enough to do much with addressable RGB LEDs. It could handle some simple on/off LEDs, or about 4 WS2812 LEDs without impacting gamepad performance. RP2040-based boards can be a good cheap option. They only have 4 analog pins but are fast enough to do a lot of addressable LEDs. Be aware that the Pi Pico and Pi Pico W only expose 3 analog input pins. The Waveshare RP2040-Zero (https://www.aliexpress.com/item/1005006031224378.html) is one example of a cheap, small RP2040 board with 4 analog pins. |
| Electronics | CD74HC4067 analog multiplexer breakout board to support additional sensor inputs (optional) | 1 | | Here's some example listings. [https://www.aliexpress.com/item/1005006160631703.html](https://www.aliexpress.com/item/1005006160631703.html) [https://www.amazon.com/HiLetgo-CD74HC4067-Channel-Multiplexer-Breakout/dp/B01DLHKLNE](https://www.amazon.com/HiLetgo-CD74HC4067-Channel-Multiplexer-Breakout/dp/B01DLHKLNE) . I didn't buy fromthese sellers. Lots of sellers have this breakout board. This allows using up to 16 independent FSRs on a board that has at least one analog pin. Useful for RP2040 based boards, even the Pi Pico. Not currently supported upstream in teejusb/fsr but there are a couple of examples of how to add support in unmerged pull requests |
| Electronics | 22AWG solid-core hookup wire | | | Buy wire wherever you want, as an example this is the listing I purchased from: [https://www.ebay.ca/itm/371370615146](https://www.ebay.ca/itm/371370615146) . It's helpful to have a few different colors but not required. |
| Electronics | 10 ft USB cable | 1 | | USB C or USB micro, make sure it matches the Arduino board you picked |
| Electronics | Resistor kit | 1 | [Amazon](https://www.amazon.com/dp/B07N1ZK8CC) | You will need one resistor per analog input pin, so 4 to 16 resistors depending on how you wire up the FSRs. The optimal resistor value will be different depending on how many FSRs are wired in parallel to the same input pin, but the value will be somewhere around 200Ω to 1000Ω. It's useful to buy a kit. |
| Electronics | Solderless breadboard | 1 | [Amazon](https://www.amazon.com/BB830-Solderless-Plug-BreadBoard-tie-Points/dp/B0040Z4QN8) | Get one with an adhesive bottom or get some double sided tape |
| Electronics | Interlink FSR 402 short with female contacts and housing | 16 | [Interlink](https://buyinterlinkelectronics.com/collections/new-standard-force-sensors/products/fsr%C2%AE-402-short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) | You can get away with just 8 if you stick to the inner corners of the panels. Also doesn't hurt to have some spares. |
| Electronics Mounting | Drop in T-Nut with 5/16-18 thread | 2 | [TNUTZ](https://www.tnutz.com/product/db-015/) | for mounting breadboard platform |
| Electronics Mounting | Button Head Socket Cap Screws 5/16-18 thread, 5/8" long | 2 | [TNUTZ](https://www.tnutz.com/product/imperial-button-head-ss/) | for mounting breadboard platform |
| Electronics Mounting | 4 inch cable ties | | [Amazon](https://www.amazon.com/Small-Tensile-Strength-Tantti-Supply/dp/B0BC1VH4XB) | for wire management |
| Tools | 1/4" Ball End Hex Allen Key | 1 | [TNUTZ](https://www.tnutz.com/product/1-4-allen/) | You will need a ball-end hex driver to install the anchor fasteners! |
| Tools | 3/16" Ball End Hex Allen Key | 1 | [TNUTZ](https://www.tnutz.com/product/3-16-allen/) | This will fit the 5/16-18 button head screws. You can use any 3/16" hex driver if you have one but why not add this inexpensive one. |
| Tools | Wire cutters | 1 | [Amazon](https://www.amazon.com/Hakko-CHP-170-Micro-Cutter/dp/B00FZPDG1K) | |
| Tools | Wire strippers | 1 | [Amazon](https://www.amazon.com/Hakko-CSP-30-1-Stripper-Maximum-Capacity/dp/B00FZPHMUG) | |
| Tools | Deburring tool | 1 | [Amazon](https://www.amazon.com/VASTOOLS-Deburring-Chamfer-Removing-Aluminum/dp/B07RBM68SP) | Use to clean up the counterbores on the extrusions, also useful for cleaning up 3D printed parts |

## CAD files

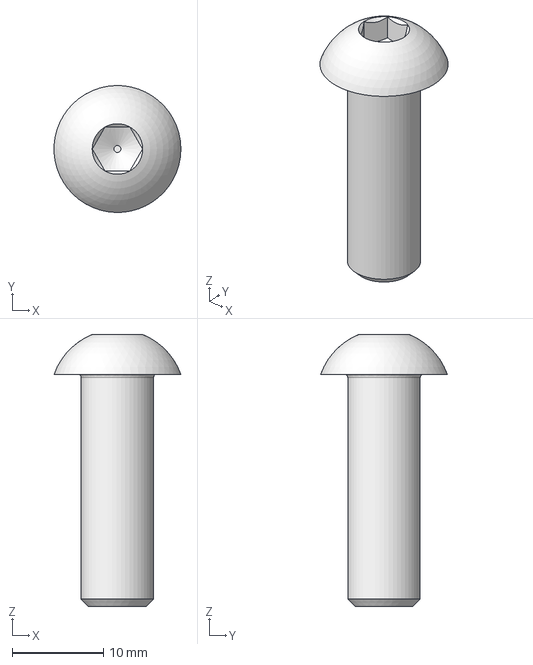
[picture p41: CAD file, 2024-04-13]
freecad/parts-and-subassemblies/sensor-assembly-mirrored.FCStd
13.9 x 13.9 x 29.8 mm

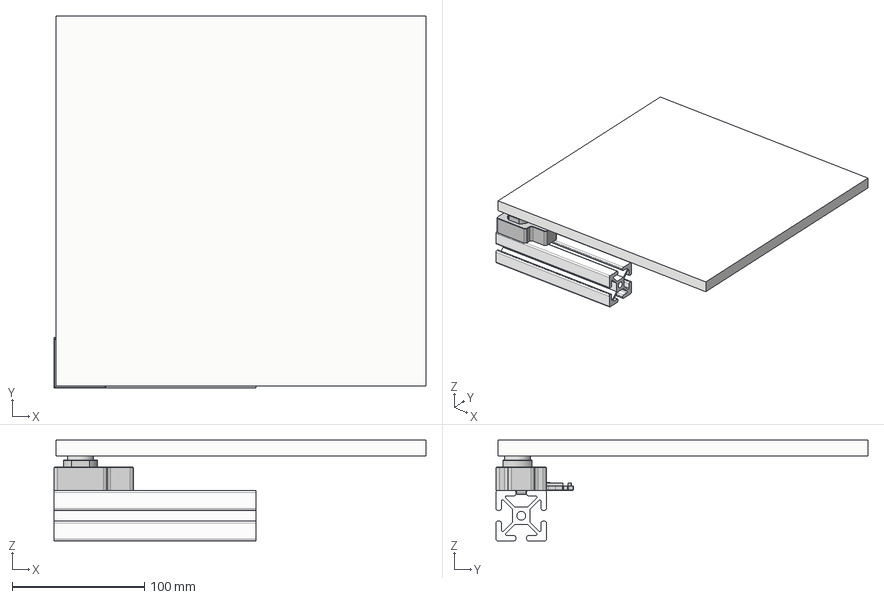
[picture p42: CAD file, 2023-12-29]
step/sensor-assembly.step
281.0 x 281.0 x 76.2 mm
Acrylic Panel
FSR Holder
FSR (Short Tail)
Rubber Bumber
Standoff (2)
Standoff Holder (4)
Velcro (1)

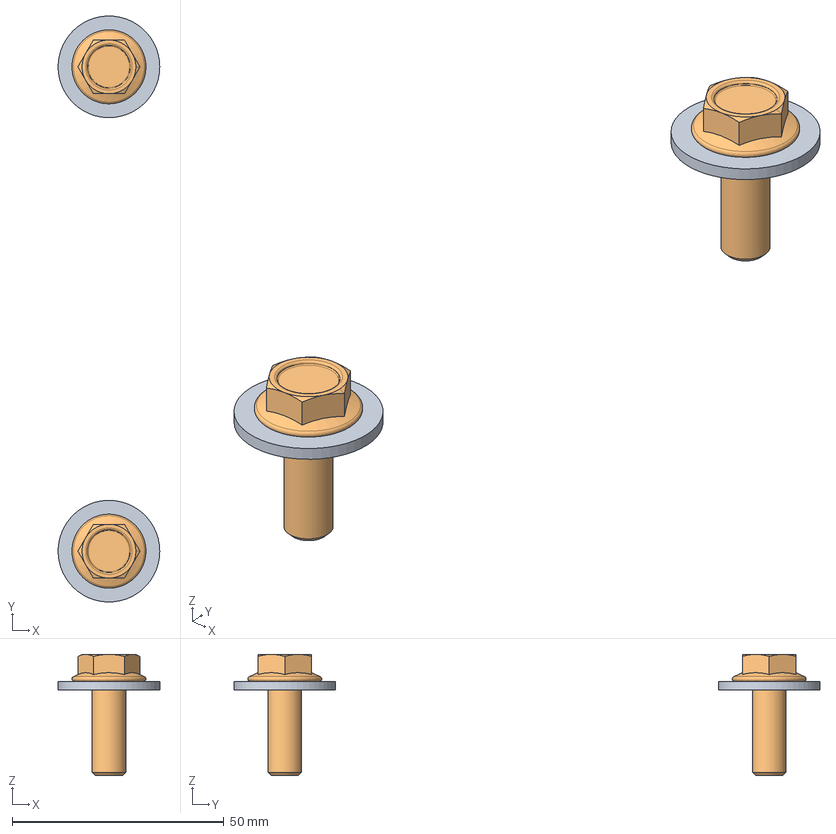
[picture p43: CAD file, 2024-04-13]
freecad/parts-and-subassemblies/bar-flange-assembly.FCStd
24.0 x 138.3 x 28.6 mm
5/16inx22.225-Screw x 2

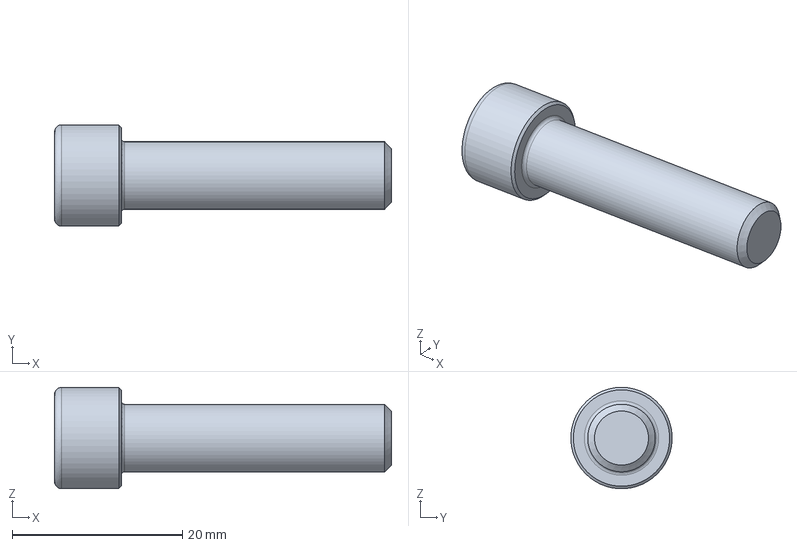
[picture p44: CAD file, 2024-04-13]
freecad/parts-and-subassemblies/anchor-fastener-assembly.FCStd
39.6 x 11.9 x 11.9 mm

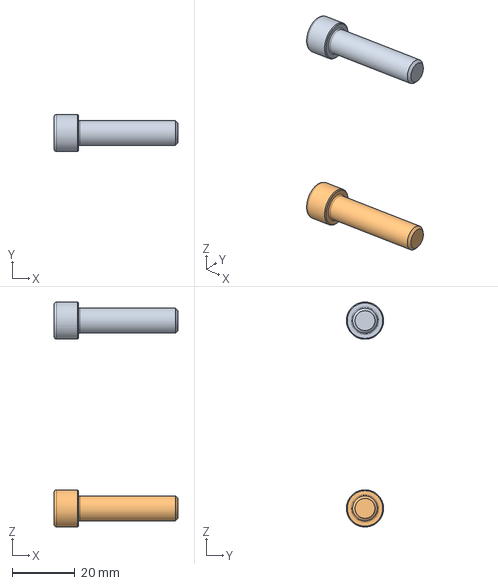
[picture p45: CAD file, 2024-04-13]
freecad/parts-and-subassemblies/double-anchor-fastener-assembly-long.FCStd
39.6 x 11.9 x 71.9 mm
5/16inx1 1/4in-Screw
5/16inx1 1/4in-Screw001

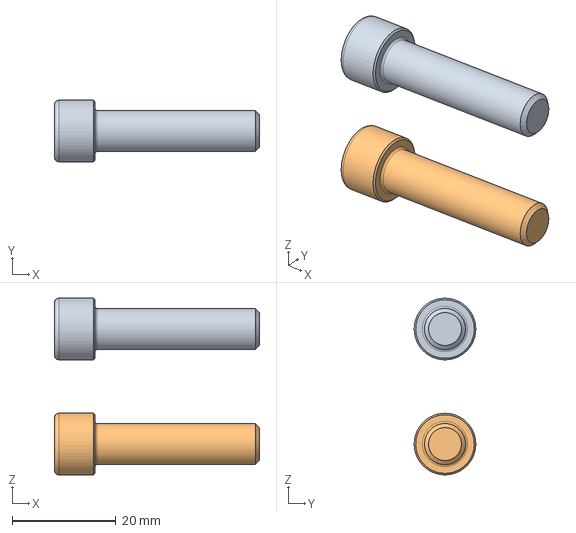
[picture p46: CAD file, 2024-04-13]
freecad/parts-and-subassemblies/double-anchor-fastener-assembly-short.FCStd
39.6 x 11.9 x 34.1 mm
5/16inx1 1/4in-Screw
5/16inx1 1/4in-Screw001

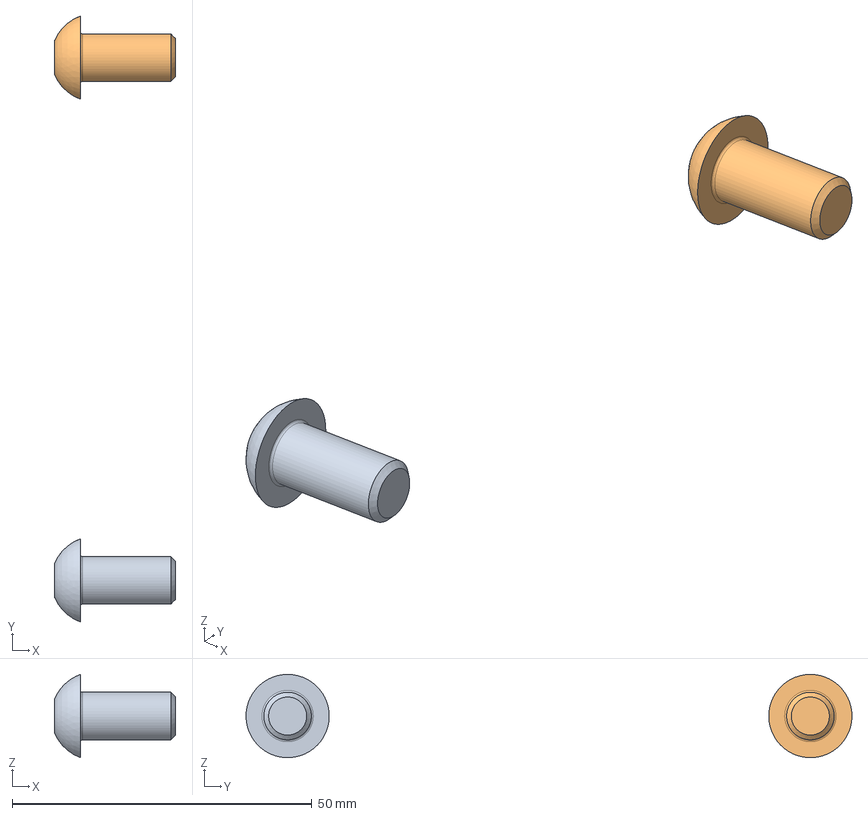
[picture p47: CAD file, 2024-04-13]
freecad/parts-and-subassemblies/breadboard-electronics-assembly.FCStd
20.2 x 101.1 x 13.9 mm
5/16inx15.875-Screw
5/16inx15.875-Screw001

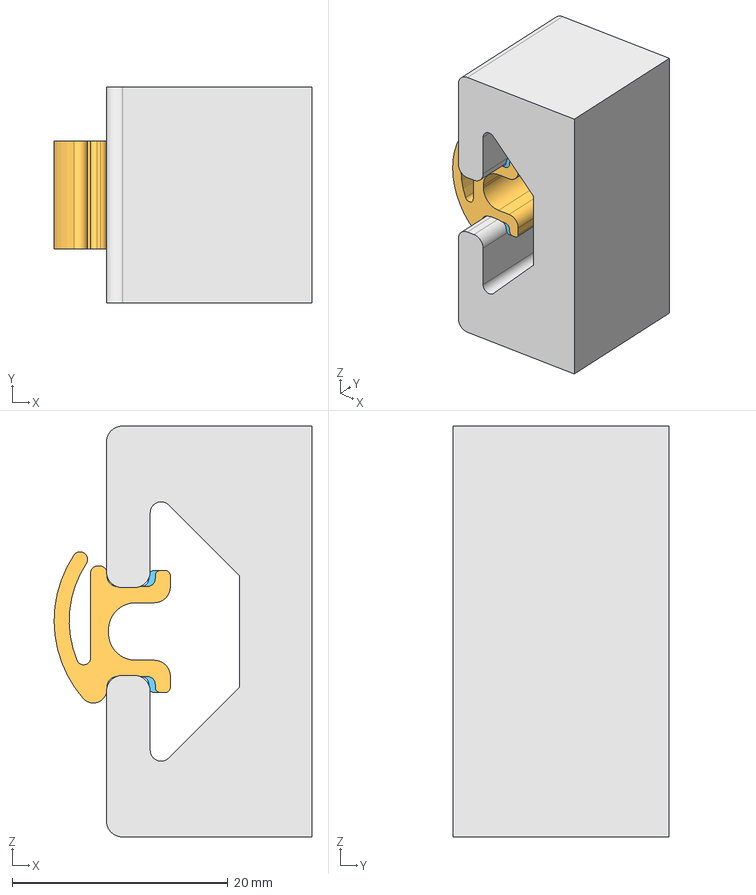
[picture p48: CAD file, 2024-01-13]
step/cable-management-clip.step
23.9 x 20.0 x 38.1 mm
Clip-1515
Clip-Motedis-4040
15 Series Extrusion Slot profile

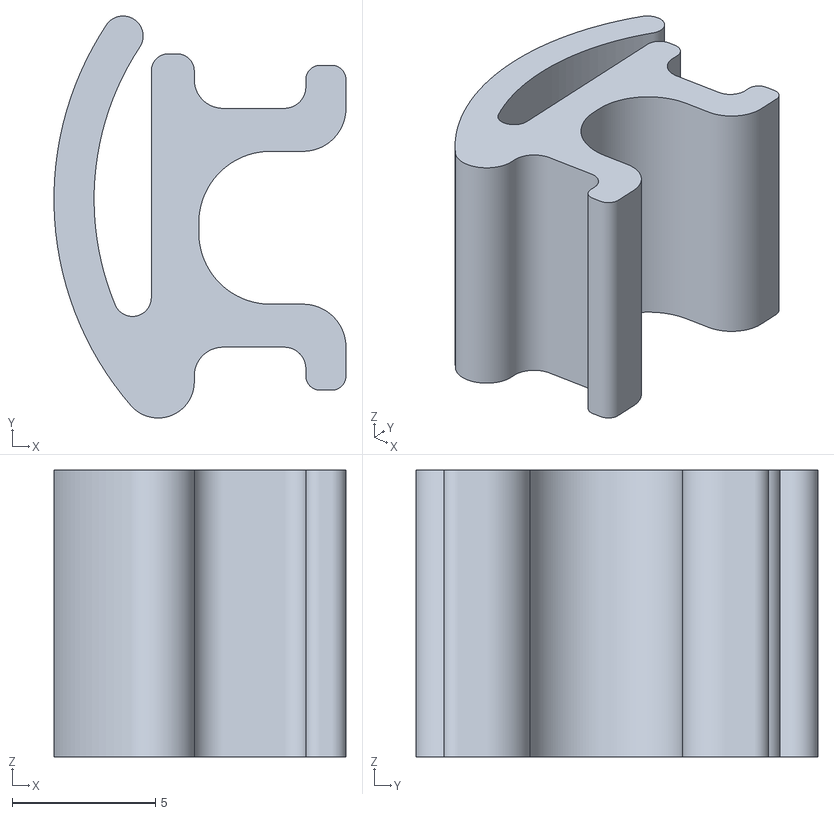
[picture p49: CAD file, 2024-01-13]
stl/cable-management-clip-15-series.stl
10.2 x 14.0 x 10.0

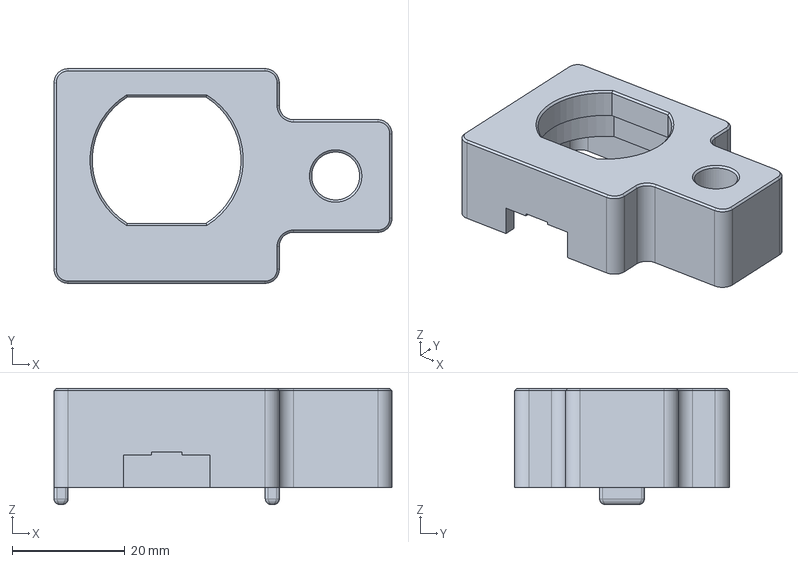
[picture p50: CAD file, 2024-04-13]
freecad/parts-and-subassemblies/standoff-holder-mirrored.FCStd
60.0 x 38.1 x 20.6 mm

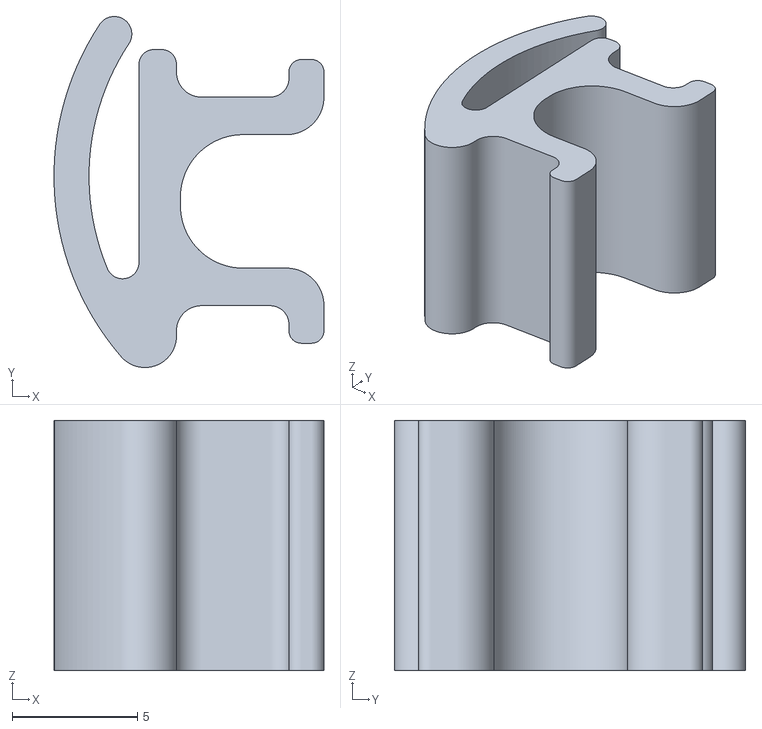
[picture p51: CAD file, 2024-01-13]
stl/cable-management-clip-motedis-40-series.stl
10.8 x 14.0 x 10.0

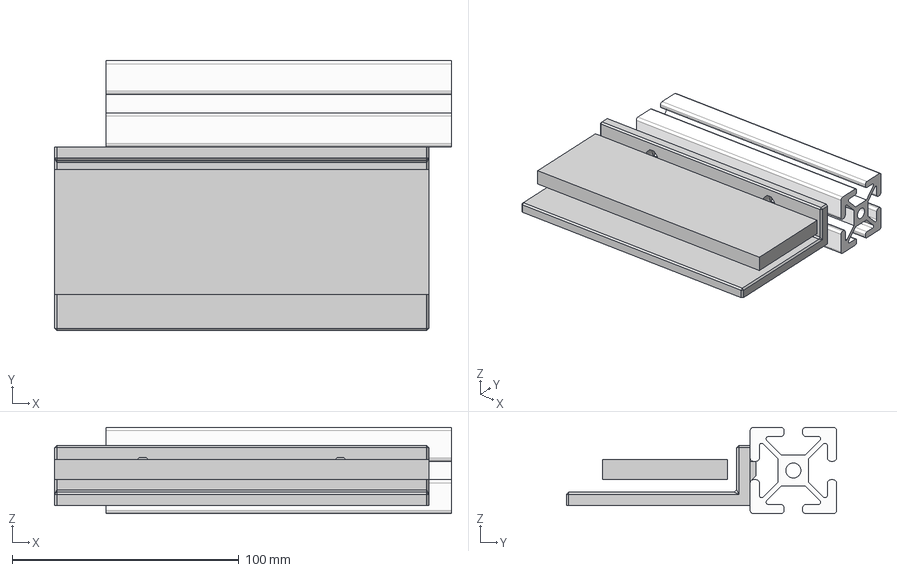
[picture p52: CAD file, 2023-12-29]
step/breadboard-platform.step
175.0 x 119.1 x 38.1 mm
Breadboard Holder
Breadboard

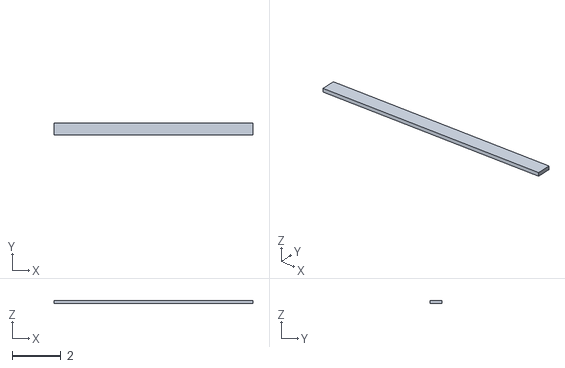
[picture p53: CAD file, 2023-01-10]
stl/tool-strut-spacer.stl
8.13 x 0.5 x 0.125

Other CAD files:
freecad/parts-and-subassemblies/sensor-assembly.FCStd
freecad/fsr-dance-pad.FCStd
freecad/parts-and-subassemblies/cable-management-clip-15-series-40-series.FCStd
stl/standoff-holder-mirrored.stl
freecad/parts-and-subassemblies/1530UL-33.375-2-dual-anchor-fasteners.FCStd
freecad/parts-and-subassemblies/1515-33.375-2-dual-anchor-fasteners.FCStd
freecad/parts-and-subassemblies/1515-33.375-ACAC-counterbore.FCStd
freecad/parts-and-subassemblies/1530UL-33.375-6-single-anchor-fasteners.FCStd
freecad/parts-and-subassemblies/1530UL-33.375-EHEH-counterbore.FCStd
freecad/parts-and-subassemblies/1530UL-33.375-FGIFGI-counterbore.FCStd
freecad/parts-and-subassemblies/1530UL-40.875.FCStd
freecad/parts-and-subassemblies/3060-33.375-6-single-anchor-fasteners.FCStd
freecad/parts-and-subassemblies/3060-33.375-KLO-counterbore.FCStd
freecad/parts-and-subassemblies/acrylic-panel.FCStd
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

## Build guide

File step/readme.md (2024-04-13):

# STEP Files

These are easier to edit than STLs when modifying parts, and more universal than FreeCAD files. If you use FreeCAD, check the [freecad](../freecad) folder also.

The STL files covered by each STEP file are listed below. Mirrored STLs are based on the non-mirrored versions. The STLs in the stl folder are oriented for printing, but the STEP files may not be.

## fsr-dance-pad.step

This is a model of the whole dance pad except for wires/cables and some of the electronics.

## breadboard-platform.step

- breadboard-platform.stl

## cable-management-clip.step

- cable-management-clip-15-series.stl
- cable-management-clip-motedis-40-series.stl

## inactive-panel-standoff.step

- inactive-panel-standoff.stl

## sensor-assembly.step

- fsr-holder.stl
- fsr-standoff.stl
- standoff-holder.stl

## flange-screw-aligner.step

- flange-screw-aligner.stl

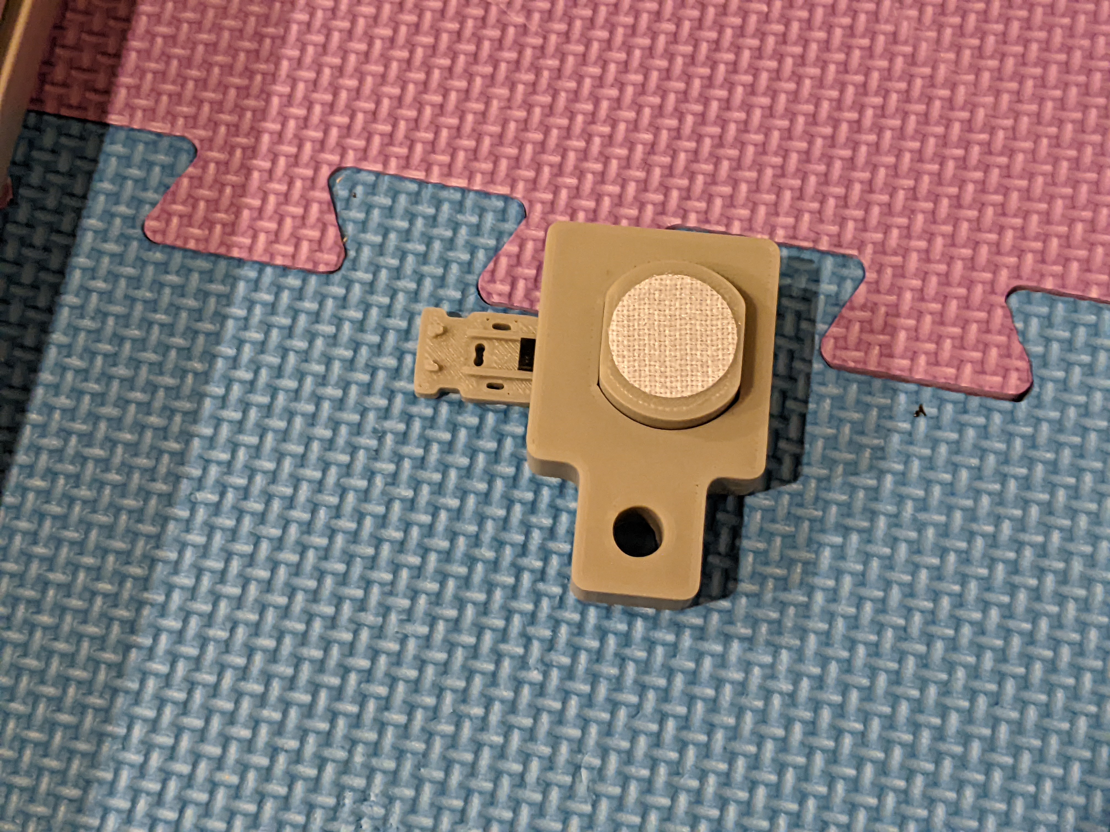
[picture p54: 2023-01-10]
images/040-active-standoff-assembly-part-3.jpg

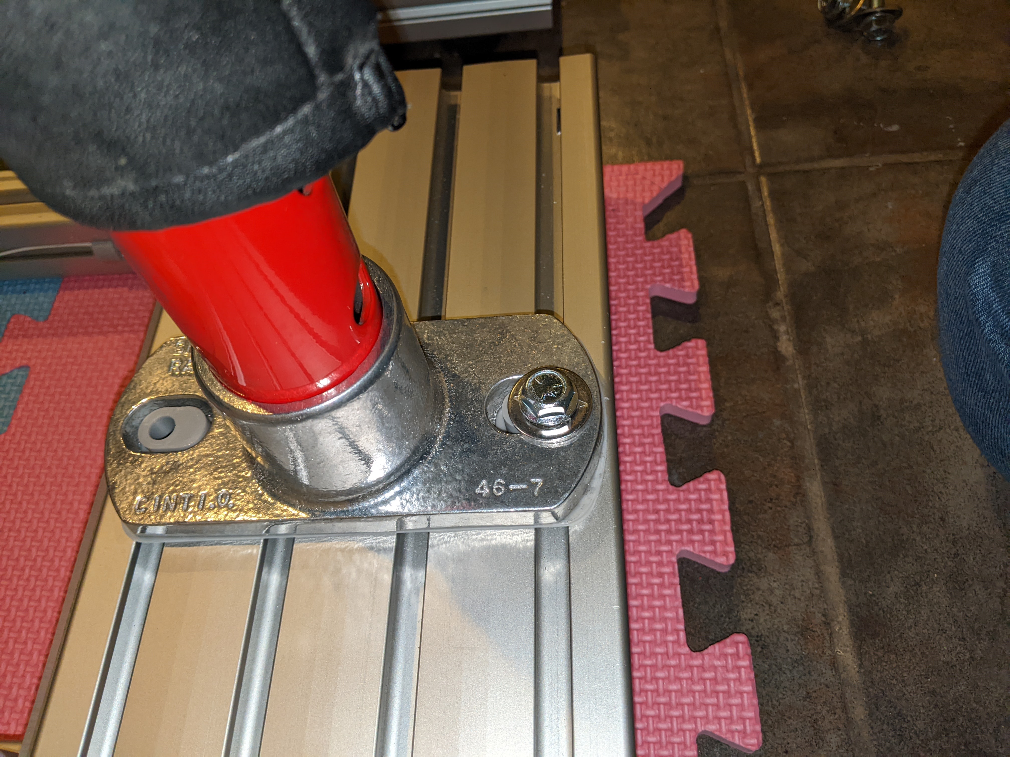
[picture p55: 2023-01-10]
images/065-bar-installation-part-3.jpg

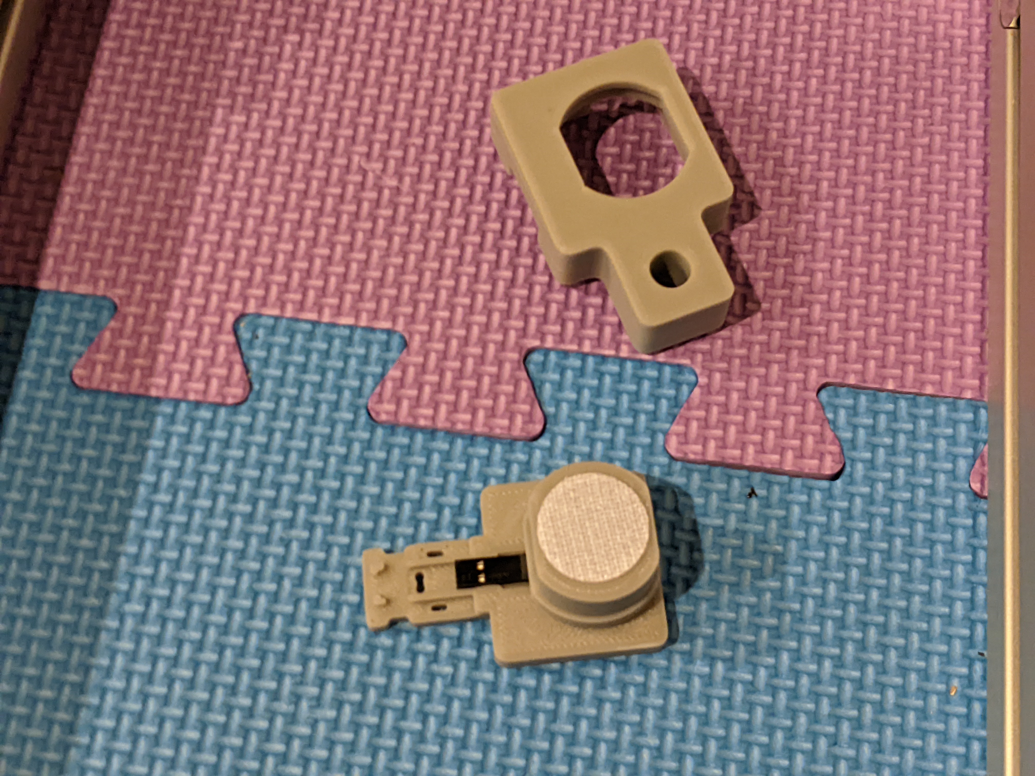
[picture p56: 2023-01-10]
images/039-active-standoff-assembly-part-2.jpg

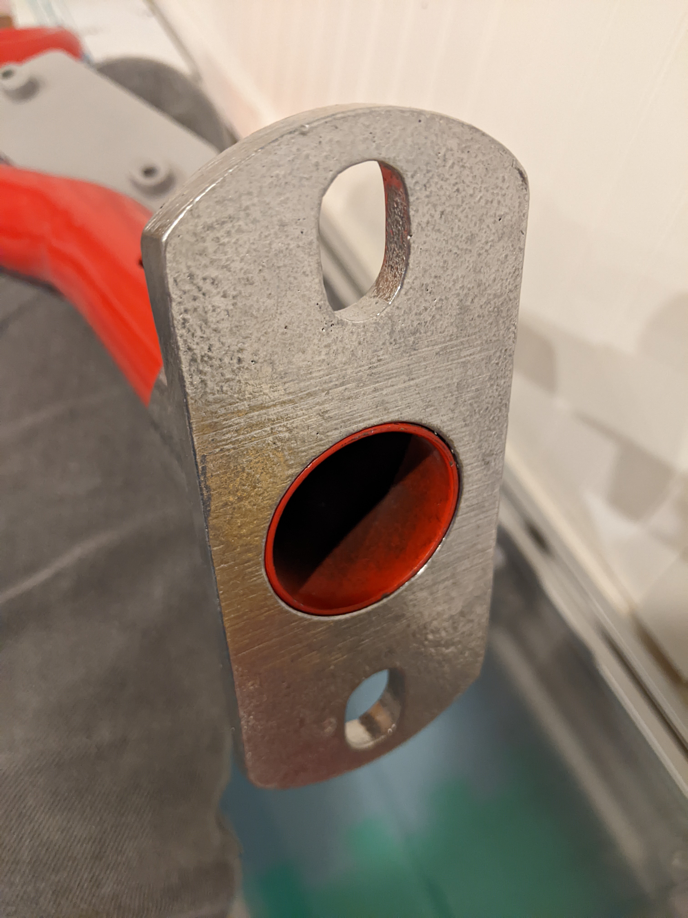
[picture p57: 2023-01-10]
images/062-flange-installation.jpg

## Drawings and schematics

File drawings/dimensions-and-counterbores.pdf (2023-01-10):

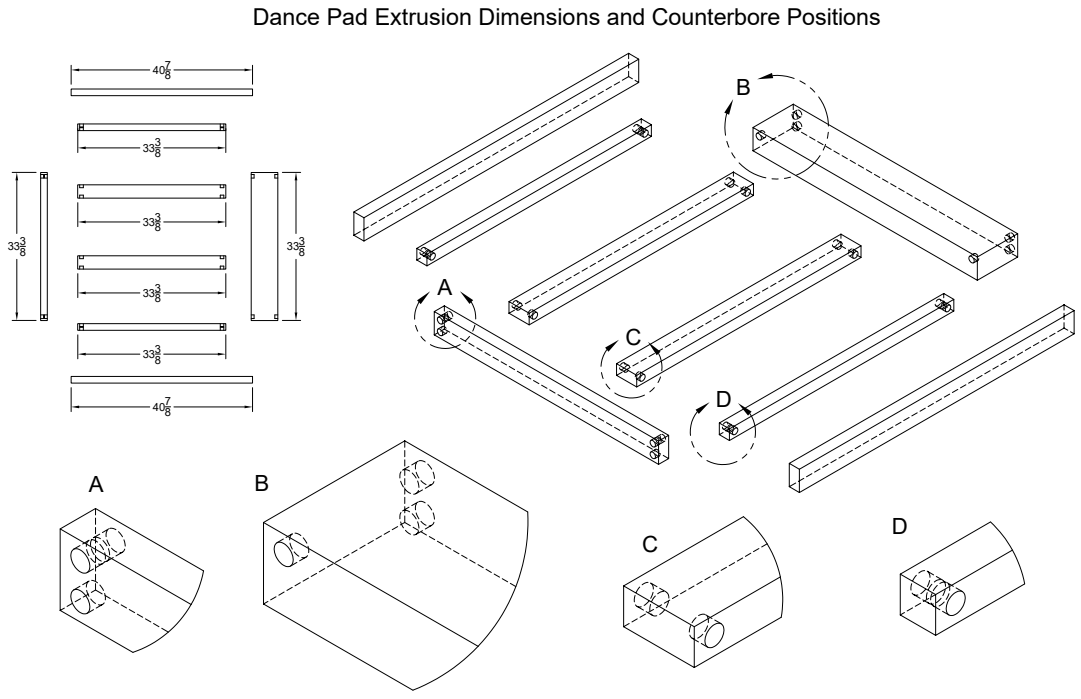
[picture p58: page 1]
Dance Pad Extrusion Dimensions and Counterbore Positions A A

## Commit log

2023-01-10 Dance pad instructions V1
    Add instructions for building pad, STLs for 3D printing, and
    step by step photos.
    [breadboard-platform.stl, flange-screw-aligner.stl, fsr-holder.stl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]
2023-12-29 Add STEP files for some parts.
    - breadboard platform
    - inactive panel standoff
    - sensor assembly
    - flange screw-aligner
    [breadboard-platform.step, flange-screw-aligner.step, inactive-panel-standoff.step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]
2024-01-13 Add cable management clip STL/STEP files
    [cable-management-clip-15-series.stl, cable-management-clip-motedis-40-series.stl, cable-management-clip.step]
2024-03-28 Mention mirrored standoff holders in README.md
2024-04-13 Add FreeCAD model and screenshot
    [1515-33.375-2-dual-anchor-fasteners.FCStd, 1515-33.375-ACAC-counterbore.FCStd, 1530UL-33.375-2-dual-anchor-fasteners.FCStd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]
2024-04-13 Add STEP file of whole dance pad, update readmes
    STEP export was originally missing the mirrored
    active sensor assemblies. Add an explicit mirrored
    sensor assembly which seems to export cleanly.
    [fsr-dance-pad.FCStd, sensor-assembly-mirrored.FCStd, standoff-holder-mirrored.FCStd]
